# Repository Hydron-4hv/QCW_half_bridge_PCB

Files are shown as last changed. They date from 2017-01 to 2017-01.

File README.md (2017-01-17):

# QCW_half_bridge_PCB
Half bridge PCB for TO-247 IGBTs, intended for DRSSTC or general use, includes optional PCB mounted CT

Design notes:
- Intended for use with "QCW_MMC_PCB" and "GDT_PCB" located in my other repositories
- Have included a lot of different holes for various mounting requirements. Hole placement is intended to allow connection to the MMC PCB via brass standoff.
- Two solder locations are provided for connecting via the CT (with jumper wire through the middle of CT). This is for flexibility when stacking 2 PCBs - can pass a connection through using a standoff through the unusued hole.
- Electrolytic cap footprints provided for 3x 25mm dia. capaciors or 2x 35mm. These are only relevant when not using a buck modulator to control bus voltage.
- Footprints provided for various different DC bus capactiors - up to 8x high voltage ceramic, up to 2x 27.5mm leg spacing film, 2x 15/22.5mm leg spacing film 
- Various Fischer Elektronik SK 481 heatsinks can be used (with clips to hold IGBTs), either 2 separate heatsinks (suggest 37.5mm length) to avoid isolation requirements, or larger 50-84mm with isolation pads behind IGBTs. In all cases use an insulated washer for heatsink mounting screw, and consider adding kapton tape or similar to top layer to add isolation between heatsink and top layer tracks.
- Option to use 2 IGBTs in parallel for each position - if this is done then care should be taken chosing gate drive sharing resistors or suitable ferrite beads to try and match switching characteristics as closely as possible (footprints provided).
- Clearance/Creepage distances (~1mm, occasionally slightly less) are marginal for running at 400-600V. Would suggest taking care with flux residue etc, and use at own risk.

Changes intended for future revisions:
- Increase clearance as possible
- Strengthen holes around IGBT gate legs with reinforcing vias

Output notes:
- 3 different "PCB Variants" have been defined and output files generated as examples:
  - Single IGBT in each of upper and lower half bridge position, no CT, 2x 37.5mm SK481 heatsinks, no electrolytic caps
  - Single IGBTs in each of upper and lower half bridge position, CT mounted, 2x 37.5mm SK481 heatsinks, 2x 35mm dia. electrolytic caps fitted
  - Dual IGBTs in each of upper and lower half bridge position, CT mounted, 2x 37.5mm SK481 heatsinks, 3x 25mm dia. electrolytic caps fitted
- The "schematic" PDFs are located under "Reference outputs" and include a 3D model for viewing in compatible software (Adobe reader works, Foxit does not, unsure about others)
- BoM outputs have been provided but are of low quality, as I did not spend time fixing up the component parameters. The schematic should give whatever information is misssing.

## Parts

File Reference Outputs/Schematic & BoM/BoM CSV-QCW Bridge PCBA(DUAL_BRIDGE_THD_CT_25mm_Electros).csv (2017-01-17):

Designator | Comment | Description | Fitted | Footprint | LibRef | Quantity
C1 | B32774 | Capacitor | Not Fitted | B32774 5uF 800V | Cap | 0
C2, C3 | 560uF | WCAP-AIL8 Aluminum Electrolytic Capacitors, 560uF | Not Fitted | WCAP-AIL8_35x47 | WCAP-AIL8, 861101486027 | 0
C4, C5, C6, C7, C11, C12, C13, C14, C16, C17 | Capacitor |  | Fitted | 2220C, 1812C, 2220C, 1812C, 2220C, 1812C, 2220C, 1812C, Cap_multi_footprint, Cap_multi_footprint | Capacitor | 10
C8, C9, C10 | 270uF | WCAP-AIL8 Aluminum Electrolytic Capacitors, 270uF | Fitted | WCAP-AIL8_25x46 | WCAP-AIL8, 861101484015 | 3
C15 | B32774 | Capacitor | Fitted | B32774 5uF 800V | Cap | 1
D1, D3, D5, D7 | 60V 2A | SS26 Schottky rectifier | Fitted | DO-214AA_(SMB-J-BEND)_UNI | SS26 | 4
D2, D4, D6, D8 | 600 W, 24 VDC | WE-TVSP Power TVS Diode, bidirectional, 600 W, 24 VDC | Fitted | DO-214AA_Bidirectional | WE-TVSP DO-214AA, 824521241 | 4
HS1, HS2 | SK481_37.5mm HS |  | Fitted | SK 481 37.5, SK 481 37.5_FLIP | SK_481_37.5 | 2
J1 | 61202021621 | WR-BHD 2.54mm Male Box Header | Fitted | 61202021621 | 61202021621 | 1
L1, L2, L3, L4 | 32O | WE-CBF SMD EMI Suppression Ferrite Bead, 1206, 32O | Fitted | WE-CBF_1206_High Speed | WE-CBF, 7427921 | 4
Q1, Q2, Q3, Q4 |  | IGBT, TO-247, Vertical | Fitted | TO-247 | TO-247_IGBT_V | 4
R3, R4, R7, R8, R11, R12, R16, R17 | Res2 | Resistor | Fitted | RES_2512 | Res2 | 8
TX1 | 56050C 50:1 CT | Murata 56050C 10A 50:1 CT | Fitted | KMP_5600_ALT | 56050C_ALT | 1

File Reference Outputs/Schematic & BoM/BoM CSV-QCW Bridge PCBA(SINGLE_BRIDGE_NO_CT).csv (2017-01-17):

Designator | Comment | Description | Fitted | Footprint | LibRef | Quantity
C1 | B32774 | Capacitor | Not Fitted | B32774 5uF 800V | Cap | 0
C2, C3 | 560uF | WCAP-AIL8 Aluminum Electrolytic Capacitors, 560uF | Not Fitted | WCAP-AIL8_35x47 | WCAP-AIL8, 861101486027 | 0
C4, C5, C6, C7, C11, C12, C13, C14, C16, C17 | Capacitor |  | Fitted | 2220C, 1812C, 2220C, 1812C, 2220C, 1812C, 2220C, 1812C, Cap_multi_footprint, Cap_multi_footprint | Capacitor | 10
C8, C9, C10 | 270uF | WCAP-AIL8 Aluminum Electrolytic Capacitors, 270uF | Not Fitted | WCAP-AIL8_25x46 | WCAP-AIL8, 861101484015 | 0
C15 | B32774 | Capacitor | Fitted | B32774 5uF 800V | Cap | 1
D1, D3 | 60V 2A | SS26 Schottky rectifier | Fitted | DO-214AA_(SMB-J-BEND)_UNI | SS26 | 2
D2, D4 | 600 W, 24 VDC | WE-TVSP Power TVS Diode, bidirectional, 600 W, 24 VDC | Fitted | DO-214AA_Bidirectional | WE-TVSP DO-214AA, 824521241 | 2
D5, D7 | 60V 2A | SS26 Schottky rectifier | Not Fitted | DO-214AA_(SMB-J-BEND)_UNI | SS26 | 0
D6, D8 | 600 W, 24 VDC | WE-TVSP Power TVS Diode, bidirectional, 600 W, 24 VDC | Not Fitted | DO-214AA_Bidirectional | WE-TVSP DO-214AA, 824521241 | 0
HS1, HS2 | SK481_37.5mm HS |  | Fitted | SK 481 37.5, SK 481 37.5_FLIP | SK_481_37.5 | 2
J1 | 61202021621 | WR-BHD 2.54mm Male Box Header | Fitted | 61202021621 | 61202021621 | 1
L1, L2 | 32O | WE-CBF SMD EMI Suppression Ferrite Bead, 1206, 32O | Fitted | WE-CBF_1206_High Speed | WE-CBF, 7427921 | 2
L3, L4 | 32O | WE-CBF SMD EMI Suppression Ferrite Bead, 1206, 32O | Not Fitted | WE-CBF_1206_High Speed | WE-CBF, 7427921 | 0
Q1, Q2 |  | IGBT, TO-247, Vertical | Fitted | TO-247 | TO-247_IGBT_V | 2
Q3, Q4 |  | IGBT, TO-247, Vertical | Not Fitted | TO-247 | TO-247_IGBT_V | 0
R3, R4, R7, R8 | Res2 | Resistor | Fitted | RES_2512 | Res2 | 4
R11, R12, R16, R17 | Res2 | Resistor | Not Fitted | RES_2512 | Res2 | 0
TX1 | 56050C 50:1 CT | Murata 56050C 10A 50:1 CT | Not Fitted | KMP_5600_ALT | 56050C_ALT | 0

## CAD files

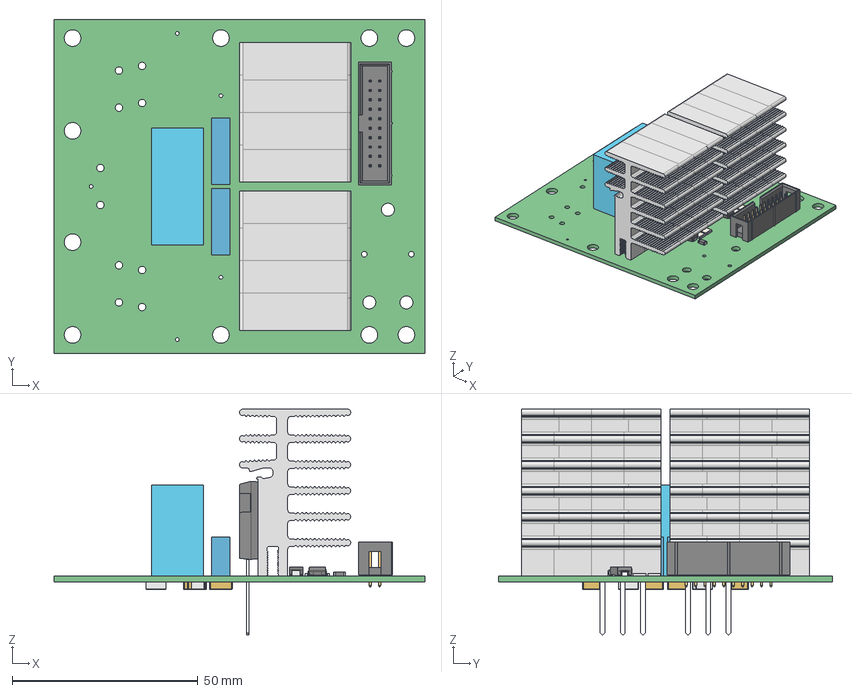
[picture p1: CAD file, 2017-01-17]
Reference Outputs/Mechanical/Export STEP Model of complete PCB_QCW Bridge PCBA-(SINGLE_BRIDGE_NO_CT).step
100.0 x 90.0 x 60.9 mm
BoardQCW_Bridge_PCBA
6120xx21621_PIN x 20
Extruded x 15
sk481 x 8
DO-214AA_Bidirectional x 2
Open_CASCADE_STEP_translator_6.8_3.1.1 x 2
Lead x 4
User_Library-TO-247_CASE_340L-02_Vertical_1 x 2
User_Library-TO-247_CASE_340L-02_Vertical_2 x 2
User_Library-TO-247_CASE_340L-02_Vertical_3 x 2
User_Library-TO-247_CASE_340L-02_Vertical_4 x 2
L\X2\00F6\X0\tende x 4
Open_CASCADE_STEP_translator_6.8_6.1.1 x 4
Open_CASCADE_STEP_translator_6.8_6.1.2 x 4
Open_CASCADE_STEP_translator_6.8_6.2.1 x 4
Open_CASCADE_STEP_translator_6.8_4.1.1 x 4
Open_CASCADE_STEP_translator_6.8_4.1.2 x 4
Open_CASCADE_STEP_translator_6.8_4.2.1 x 4

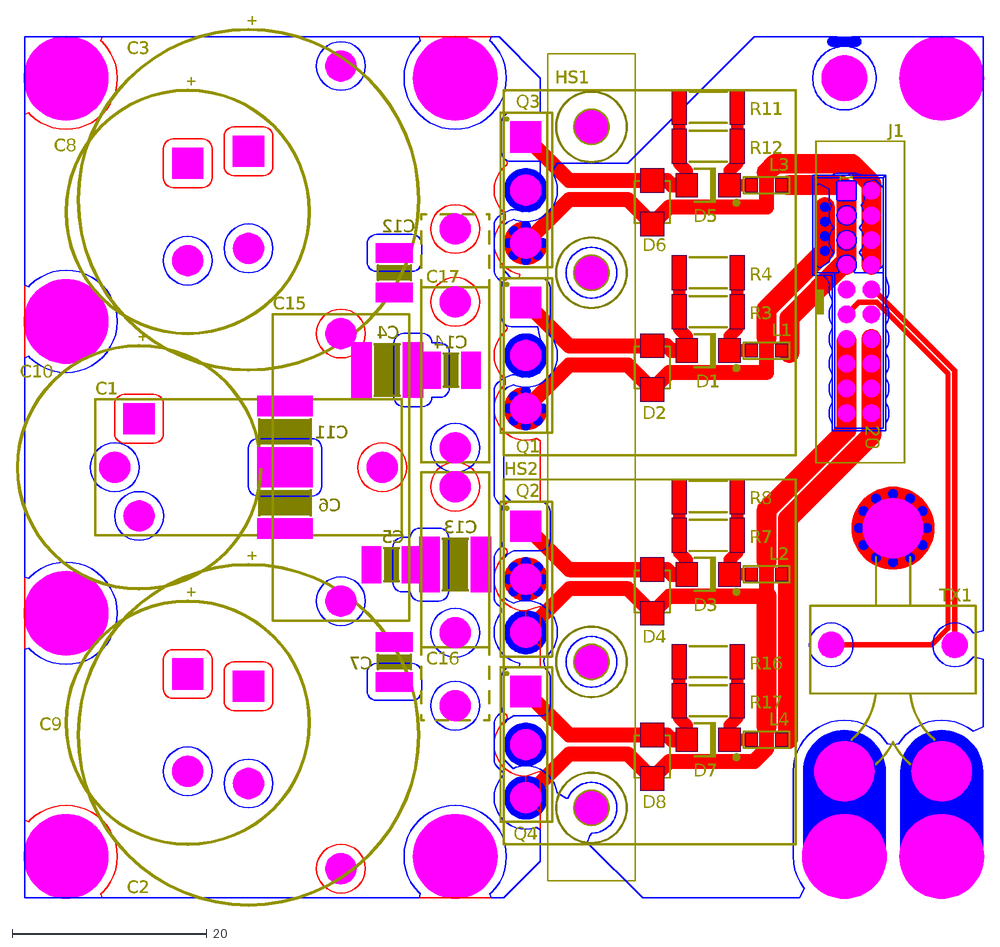
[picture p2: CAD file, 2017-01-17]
Reference Outputs/Mechanical/QCW Bridge PCBA.DXF
C3
C2
D7
TX1
J1
R17
R16
R12
R11
R8
R7
R4
R3
HS2
HS1
D8
D6
D5
Q4
Q3
D4
D3
D2
D1
Q1
Q2
C1
L1
L2
L3
L4
C4
C5
C6
C7
C8
C9
C10
C11
C12
C13
C14
C15
C16
C17

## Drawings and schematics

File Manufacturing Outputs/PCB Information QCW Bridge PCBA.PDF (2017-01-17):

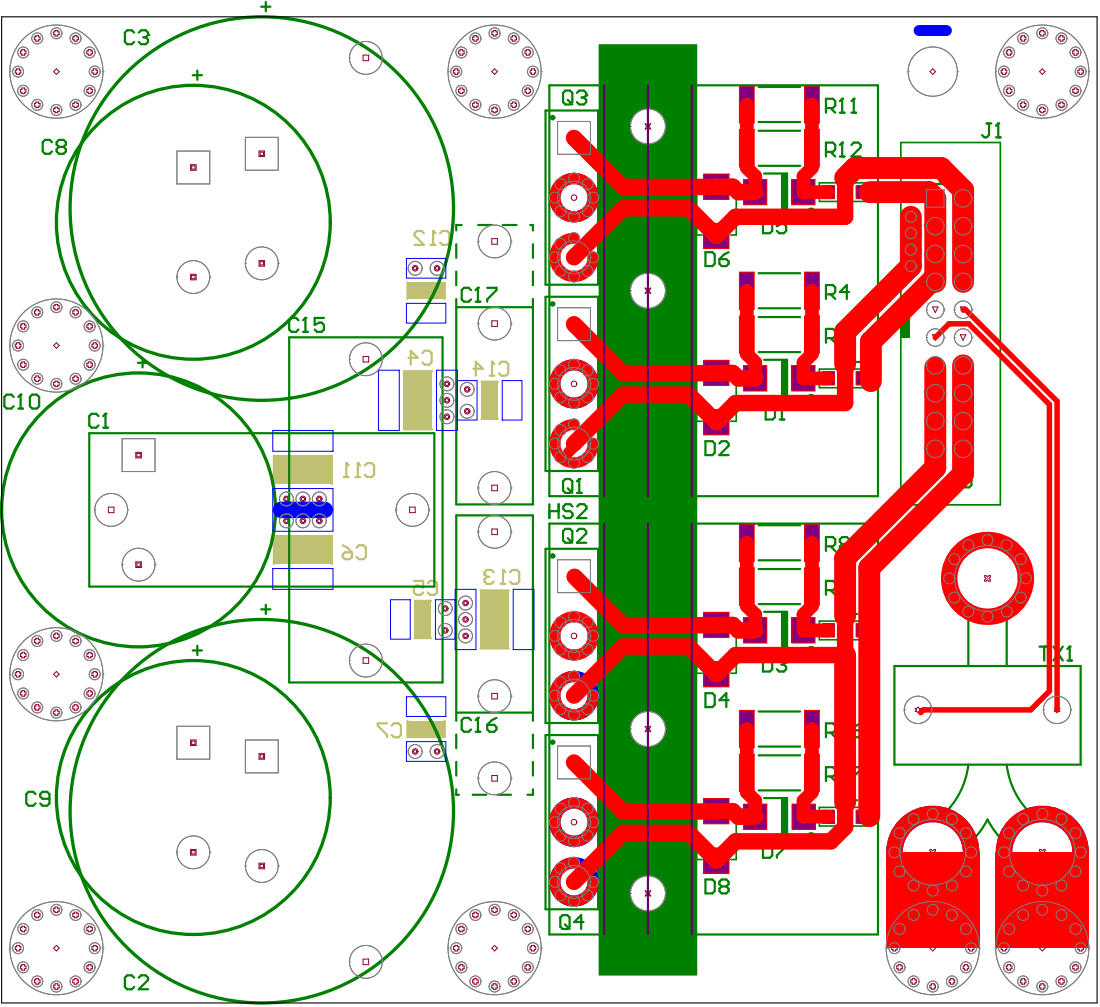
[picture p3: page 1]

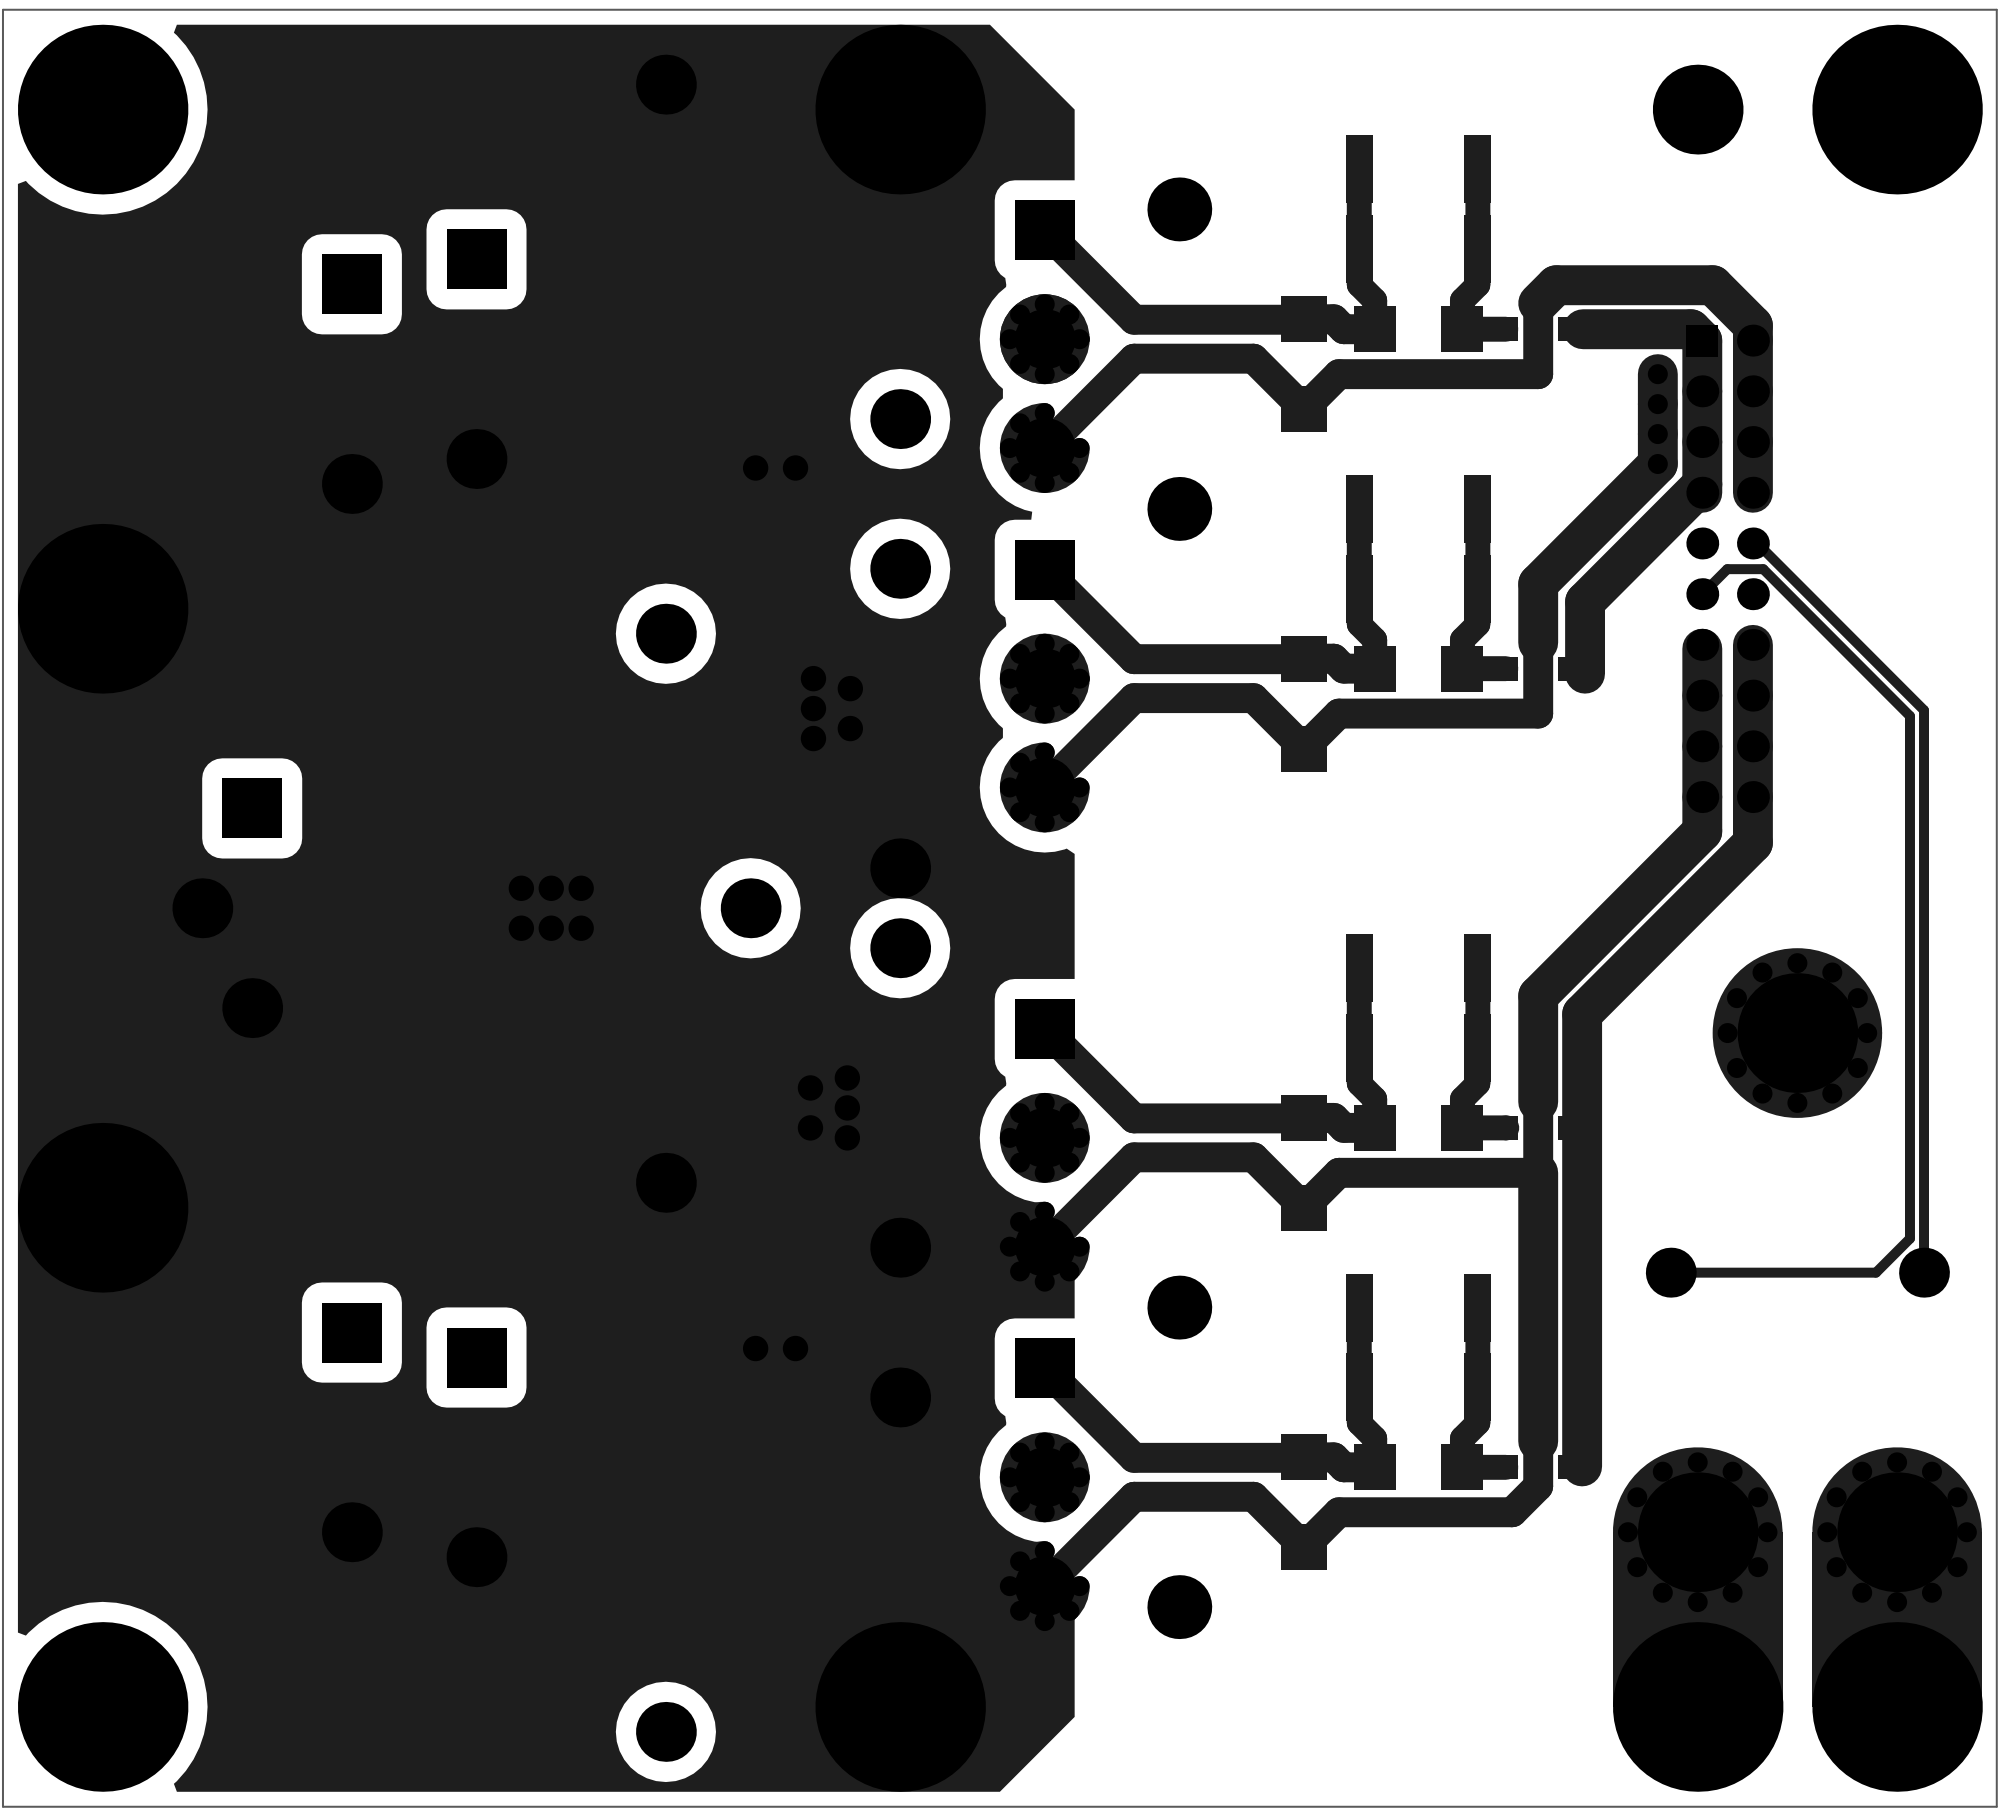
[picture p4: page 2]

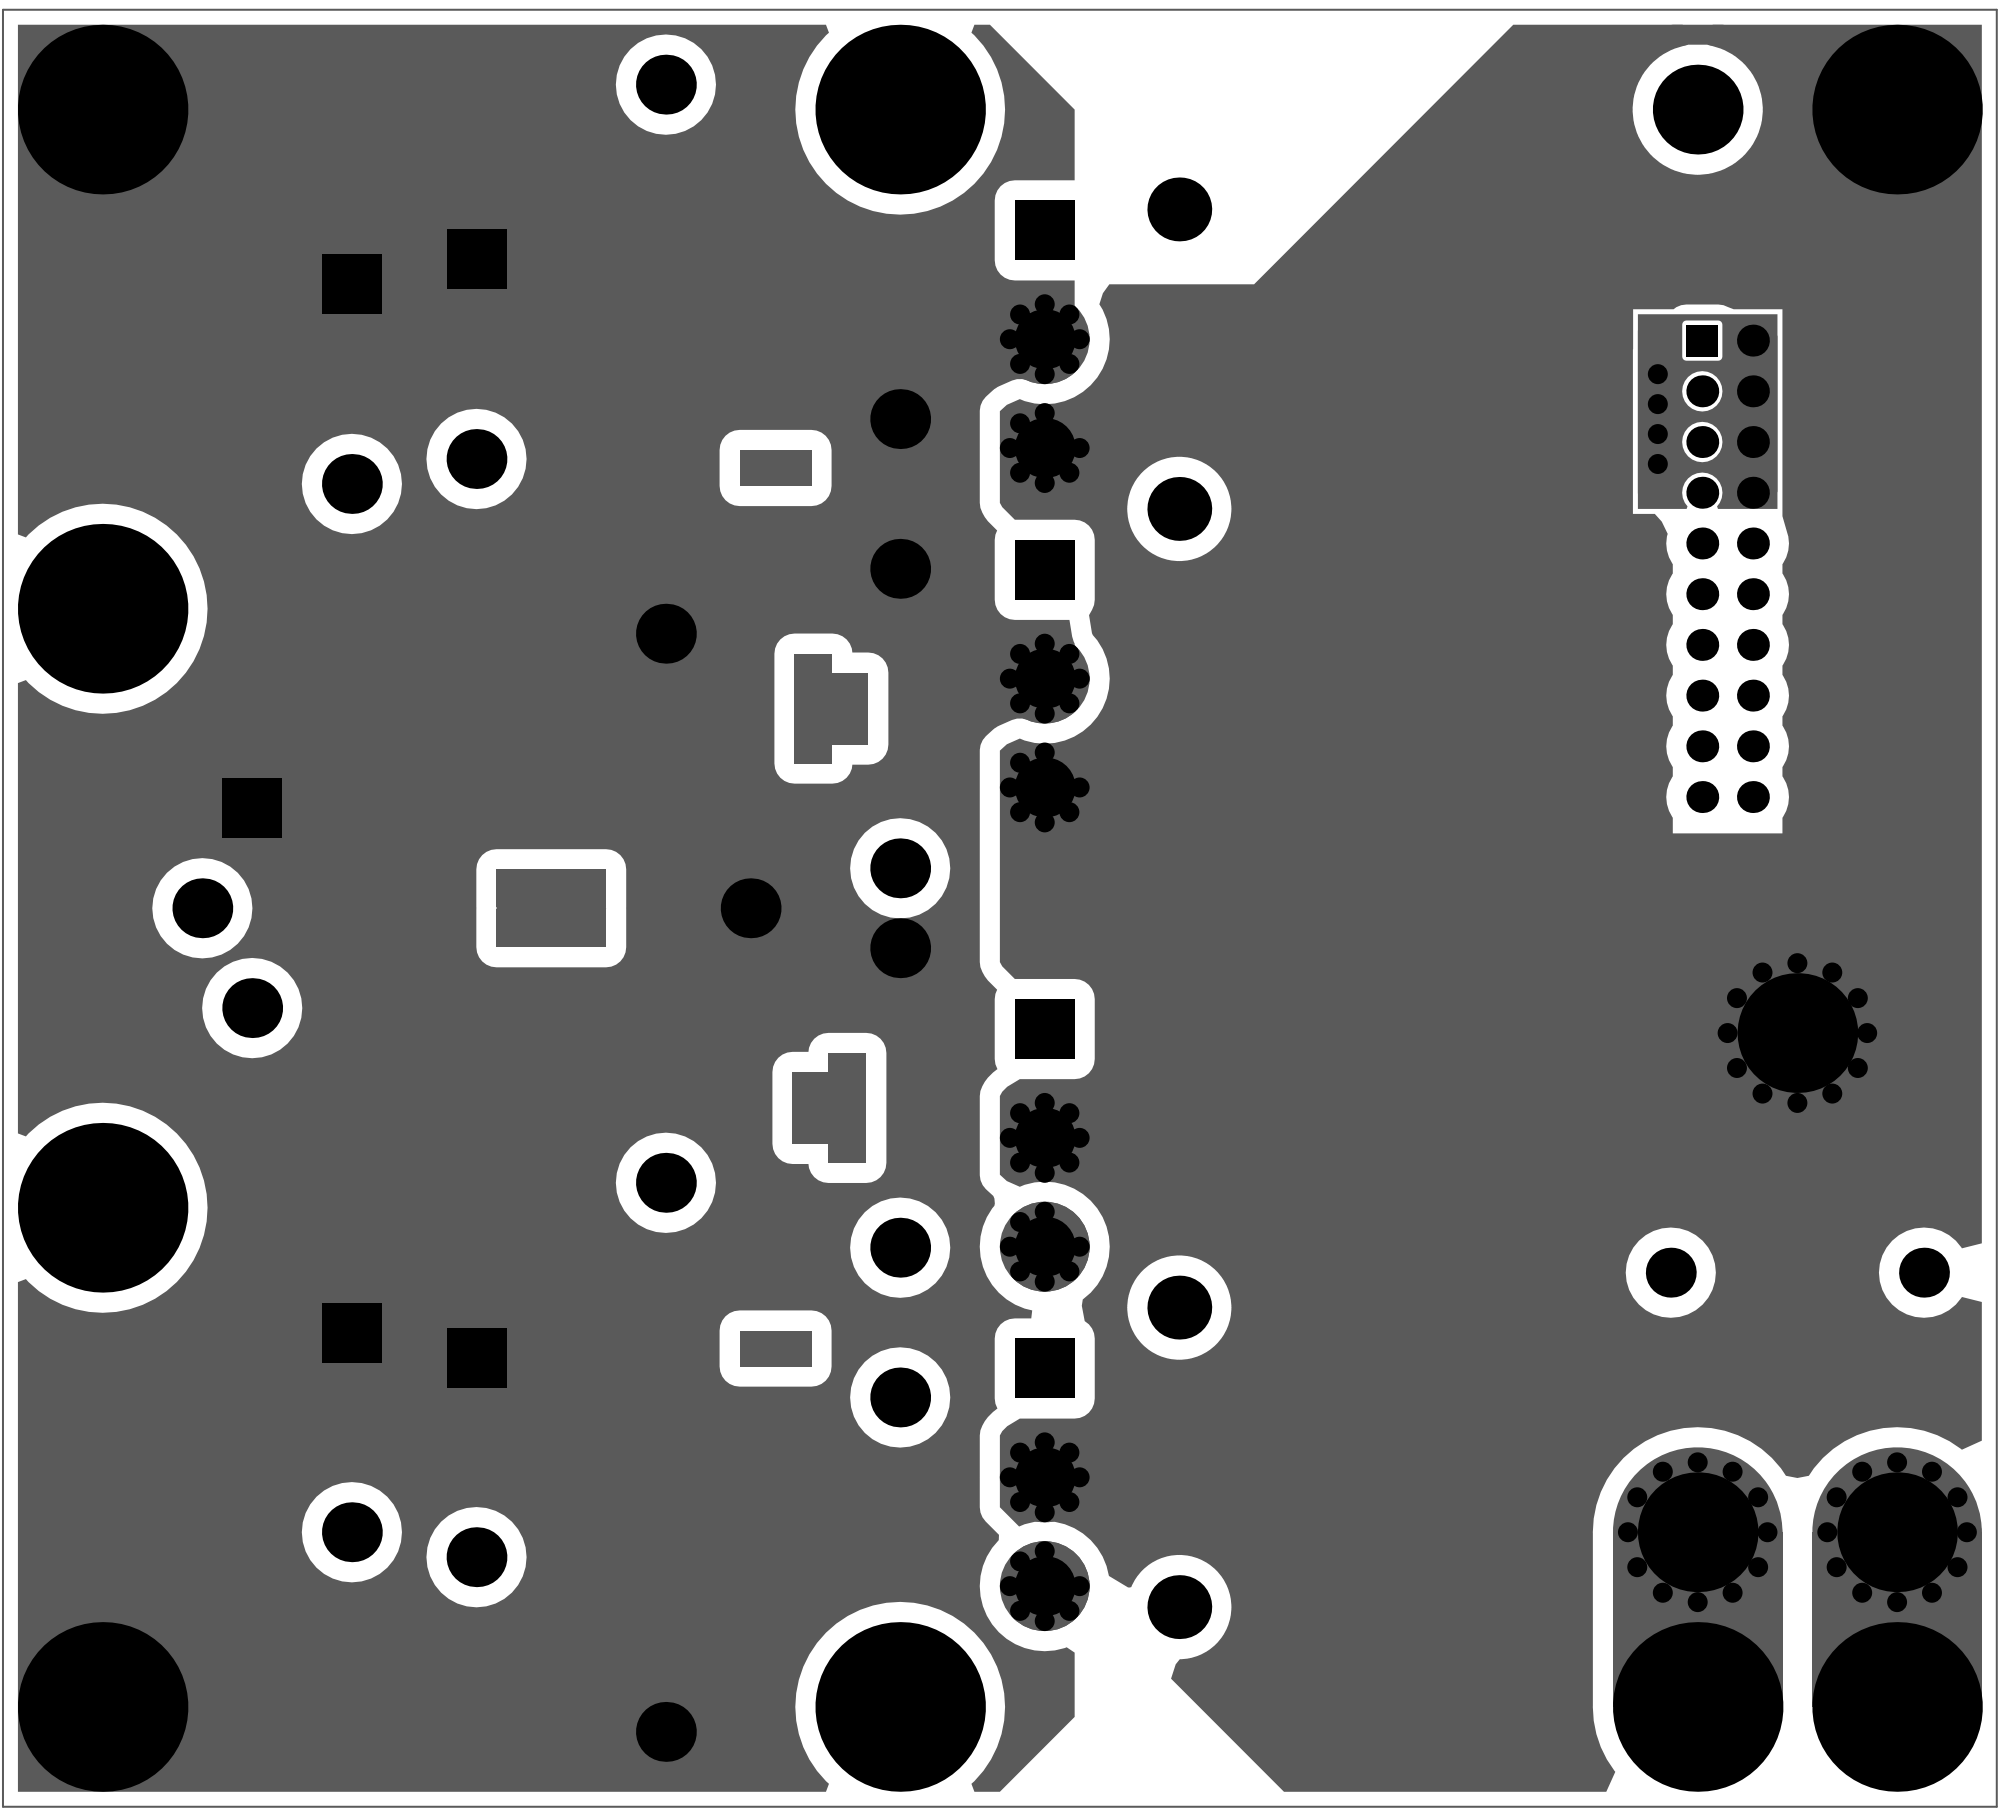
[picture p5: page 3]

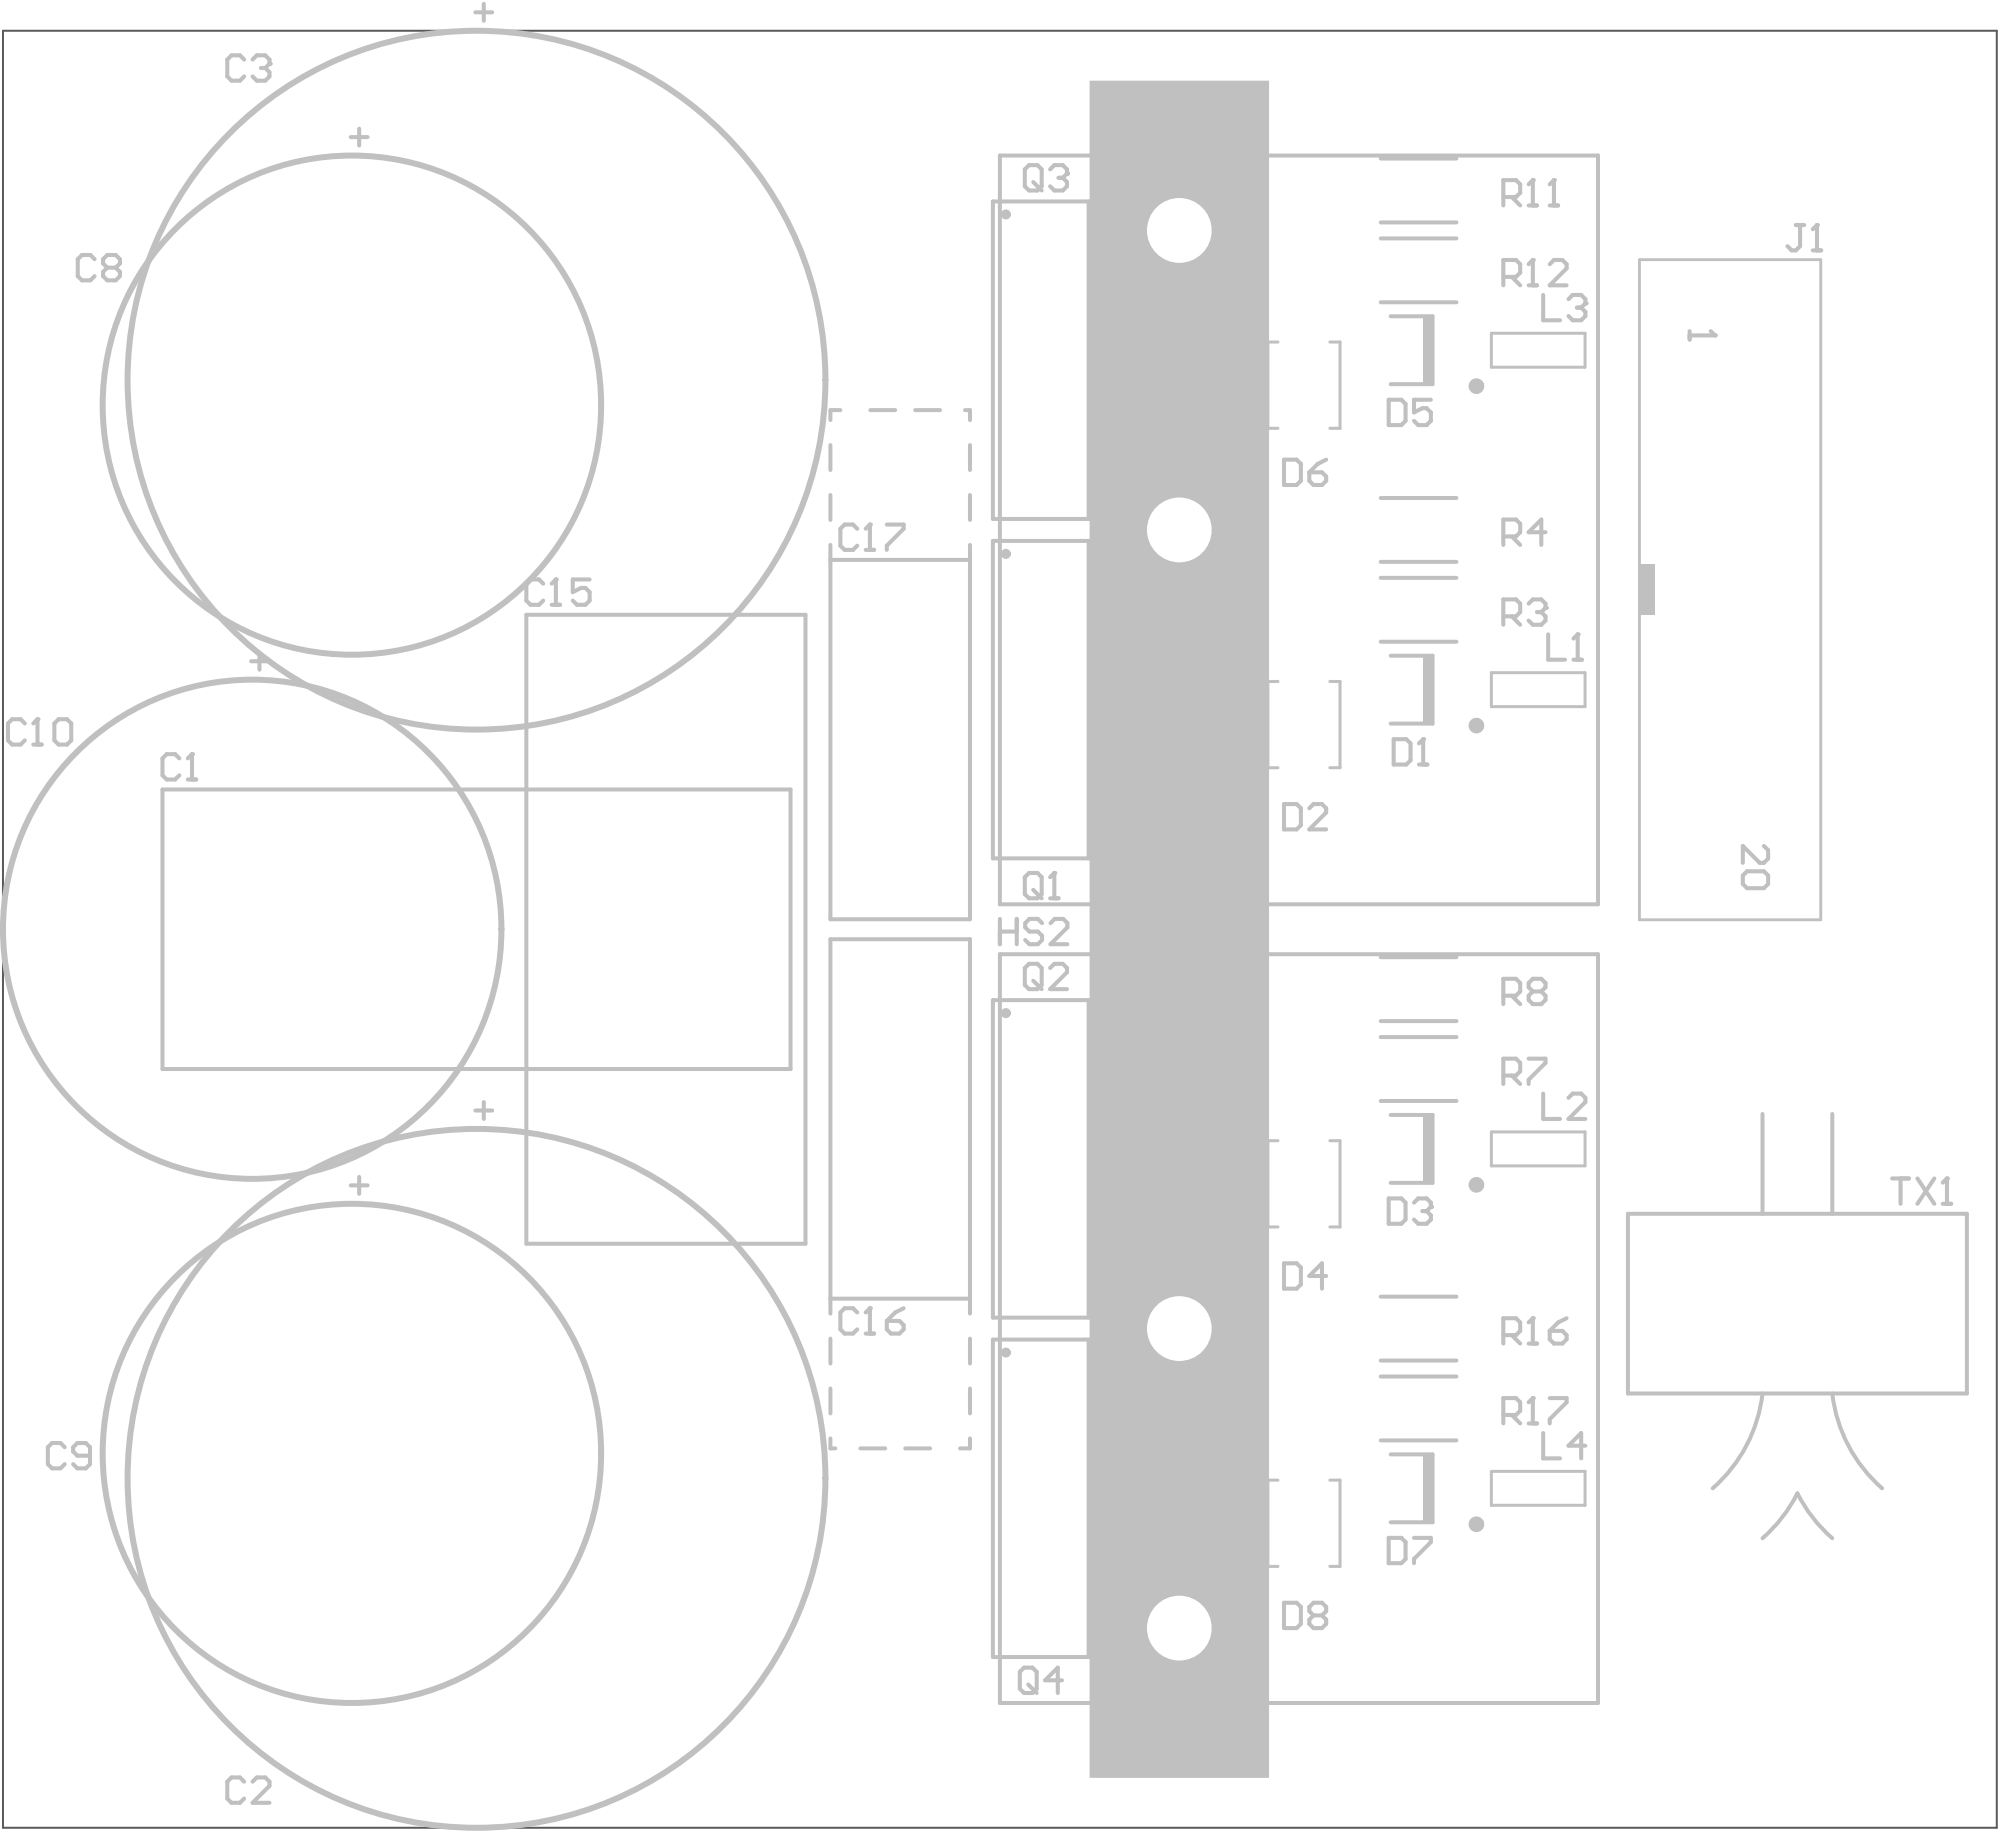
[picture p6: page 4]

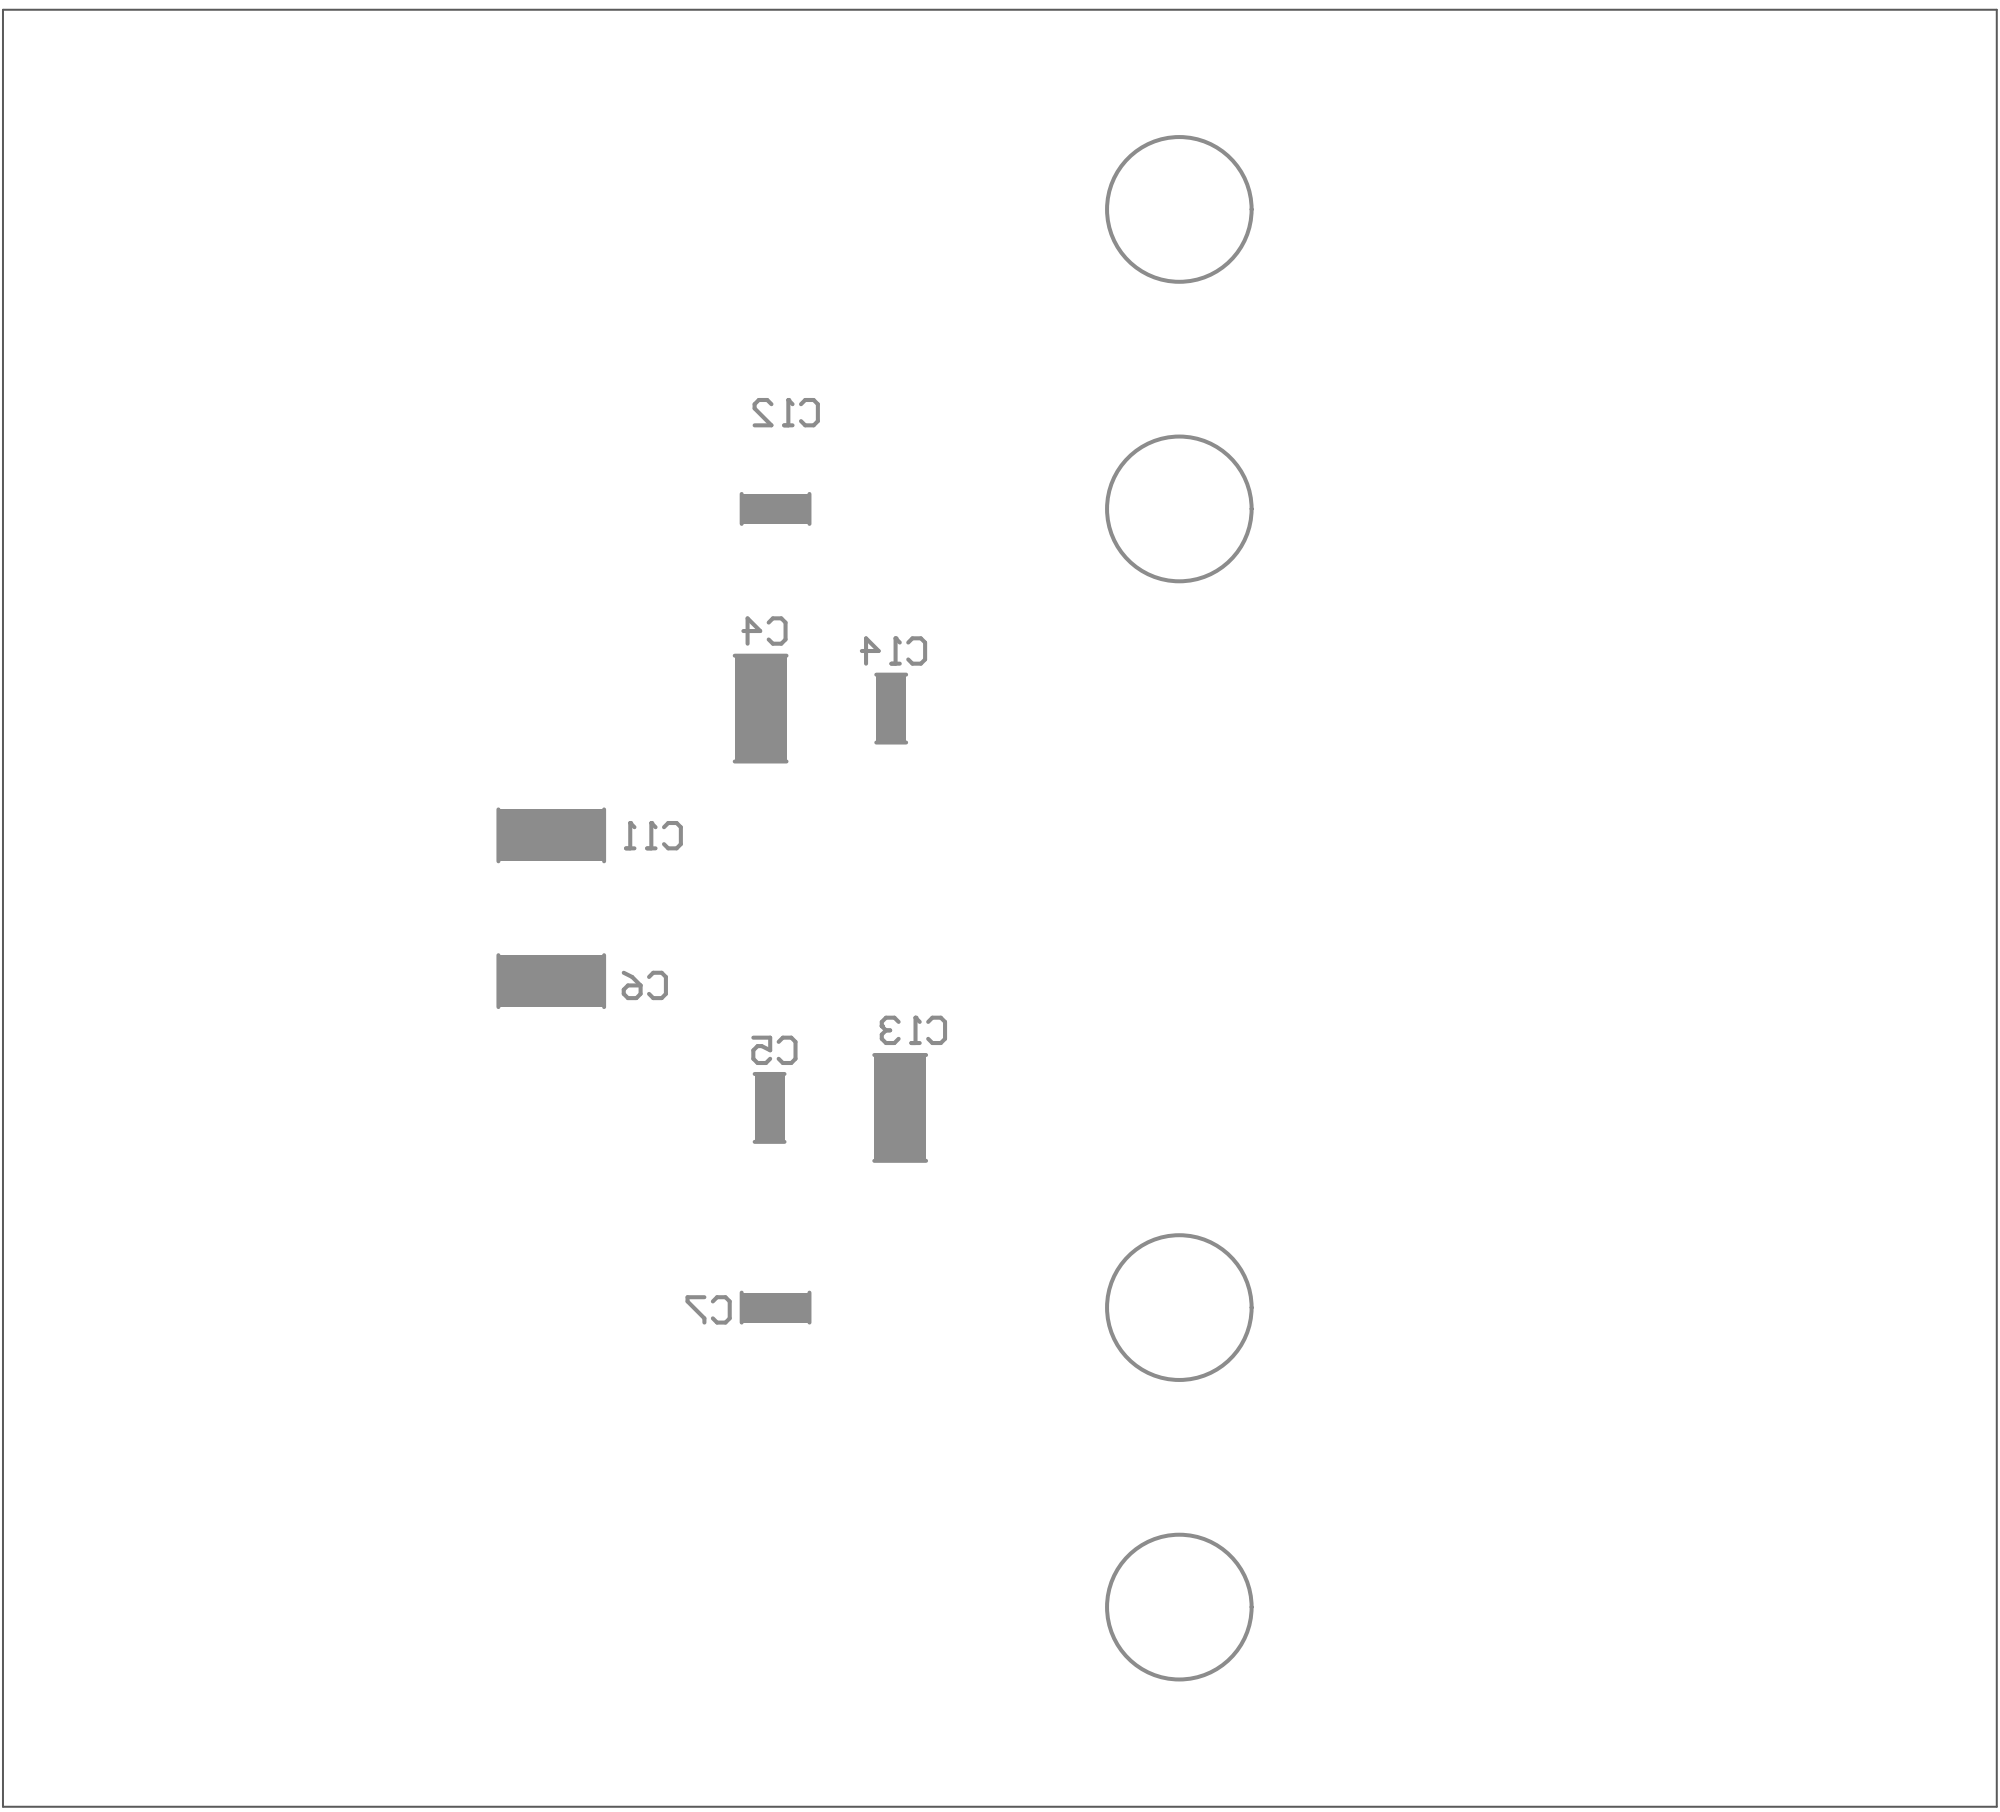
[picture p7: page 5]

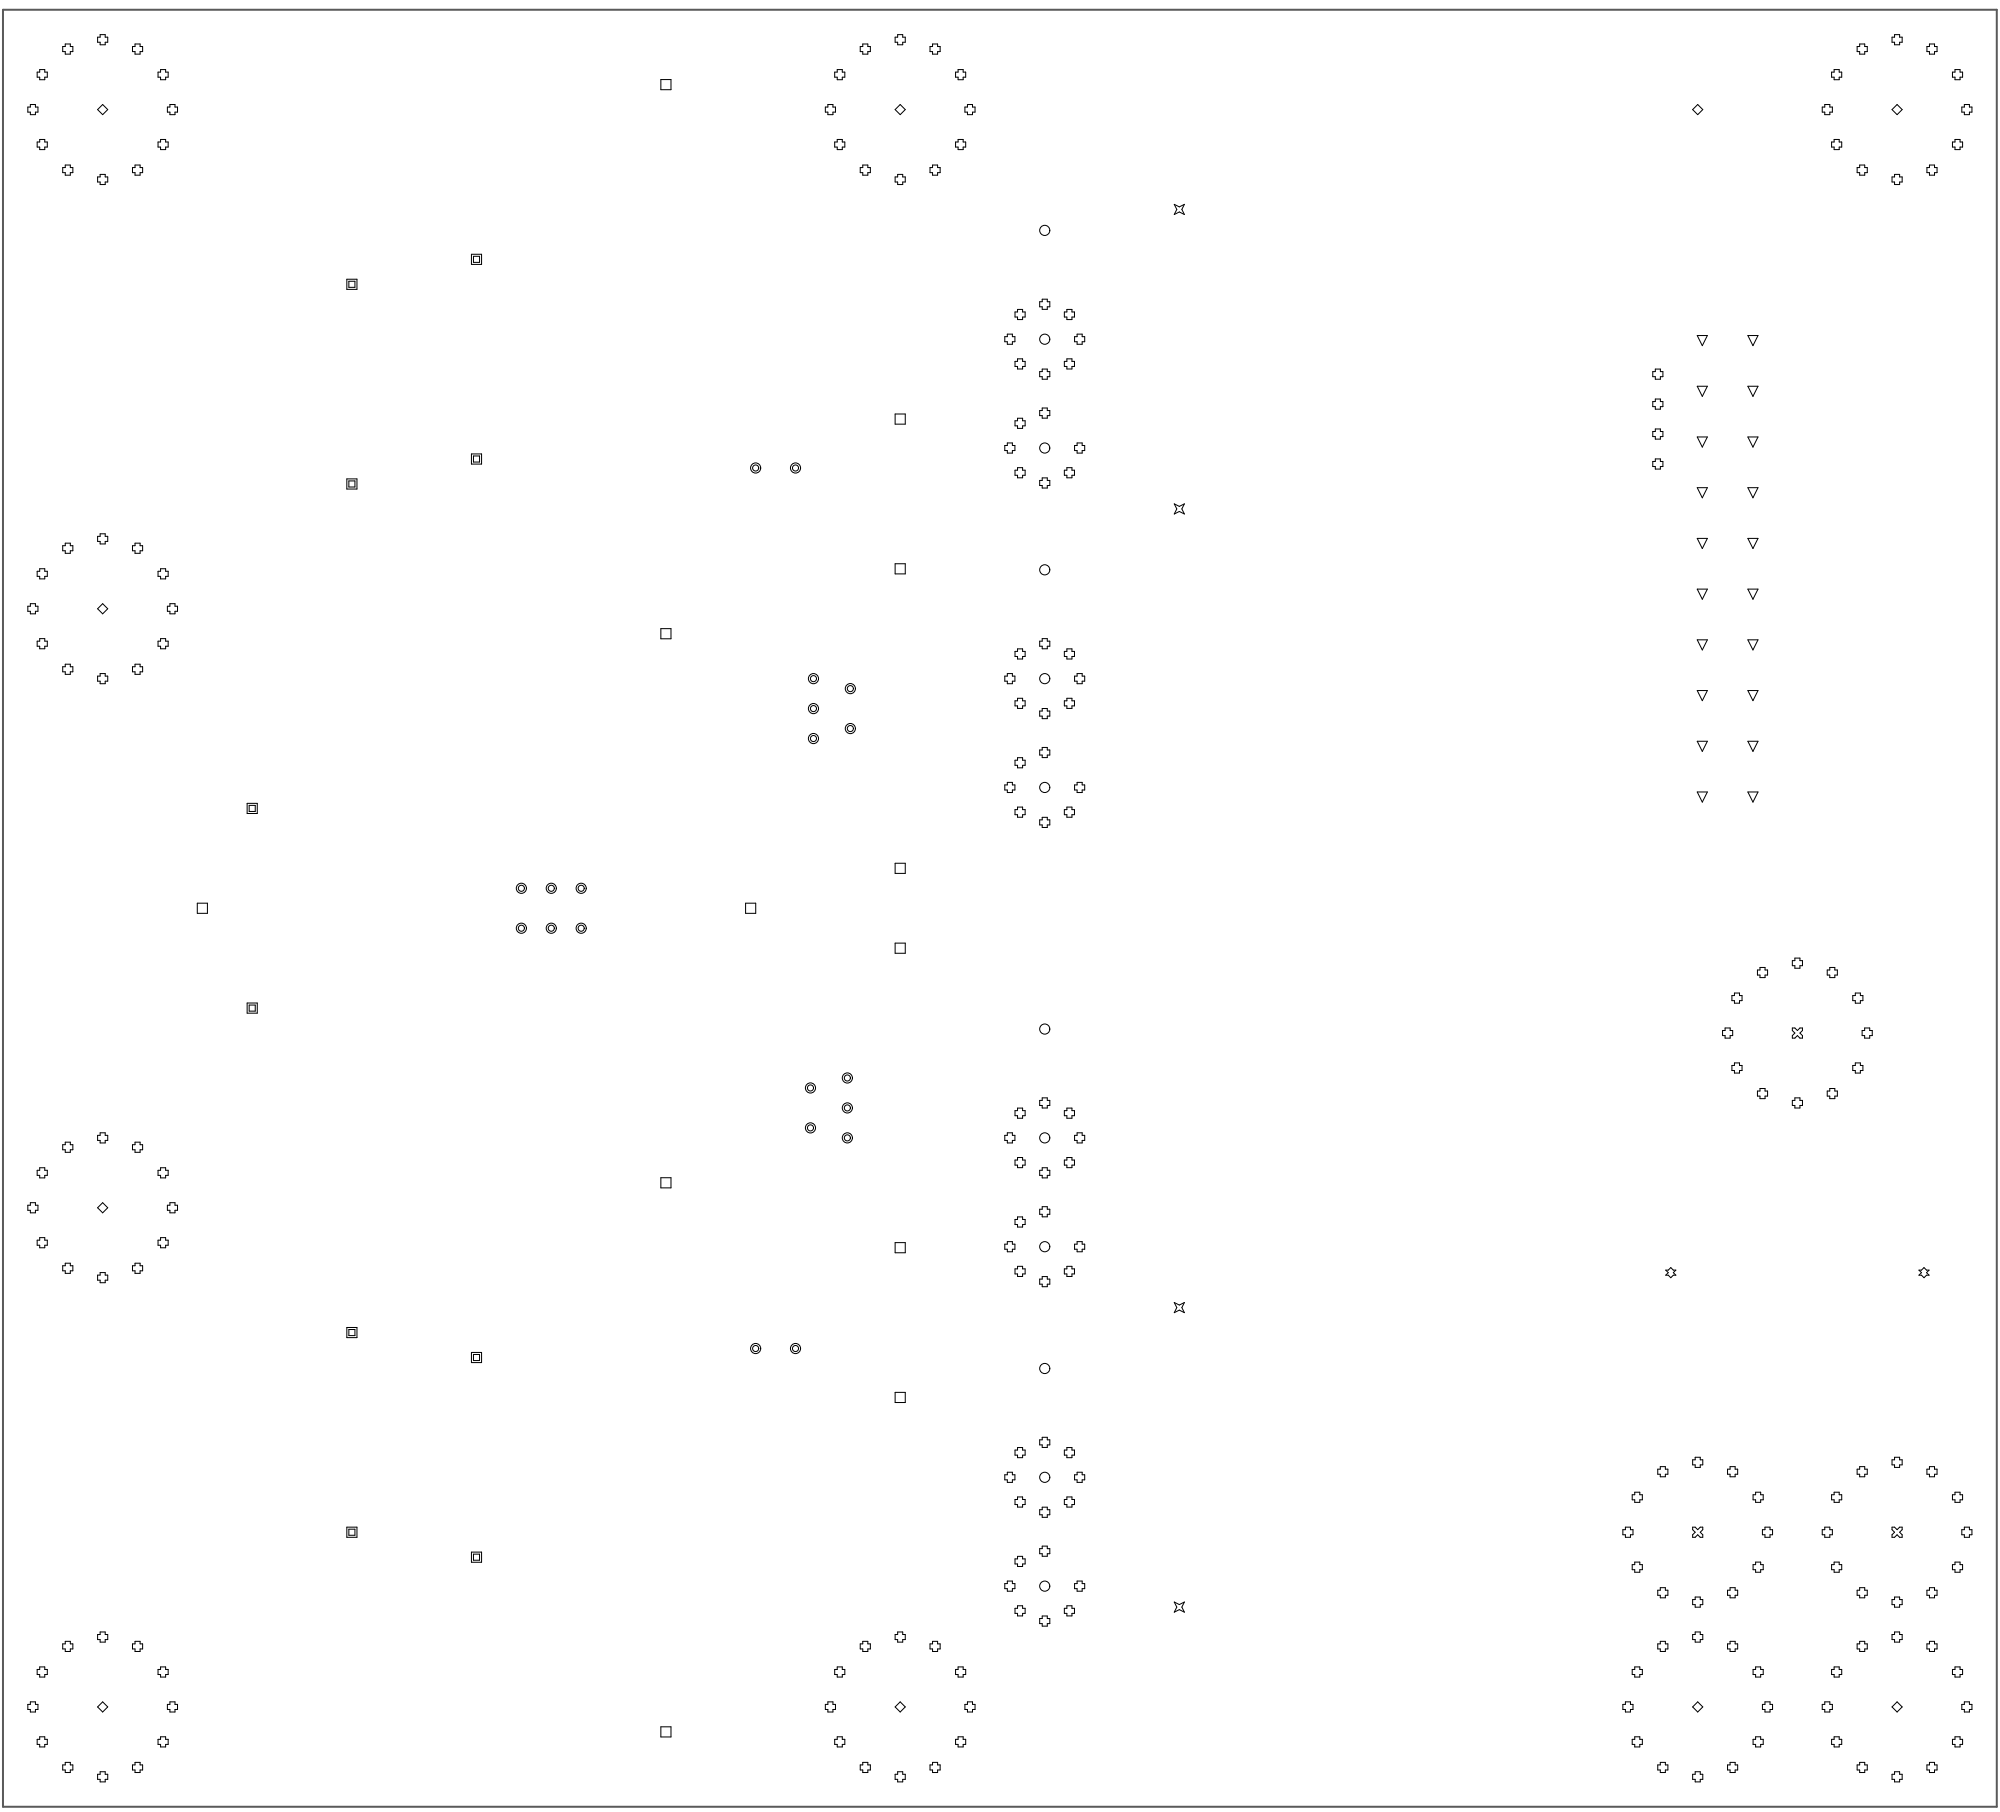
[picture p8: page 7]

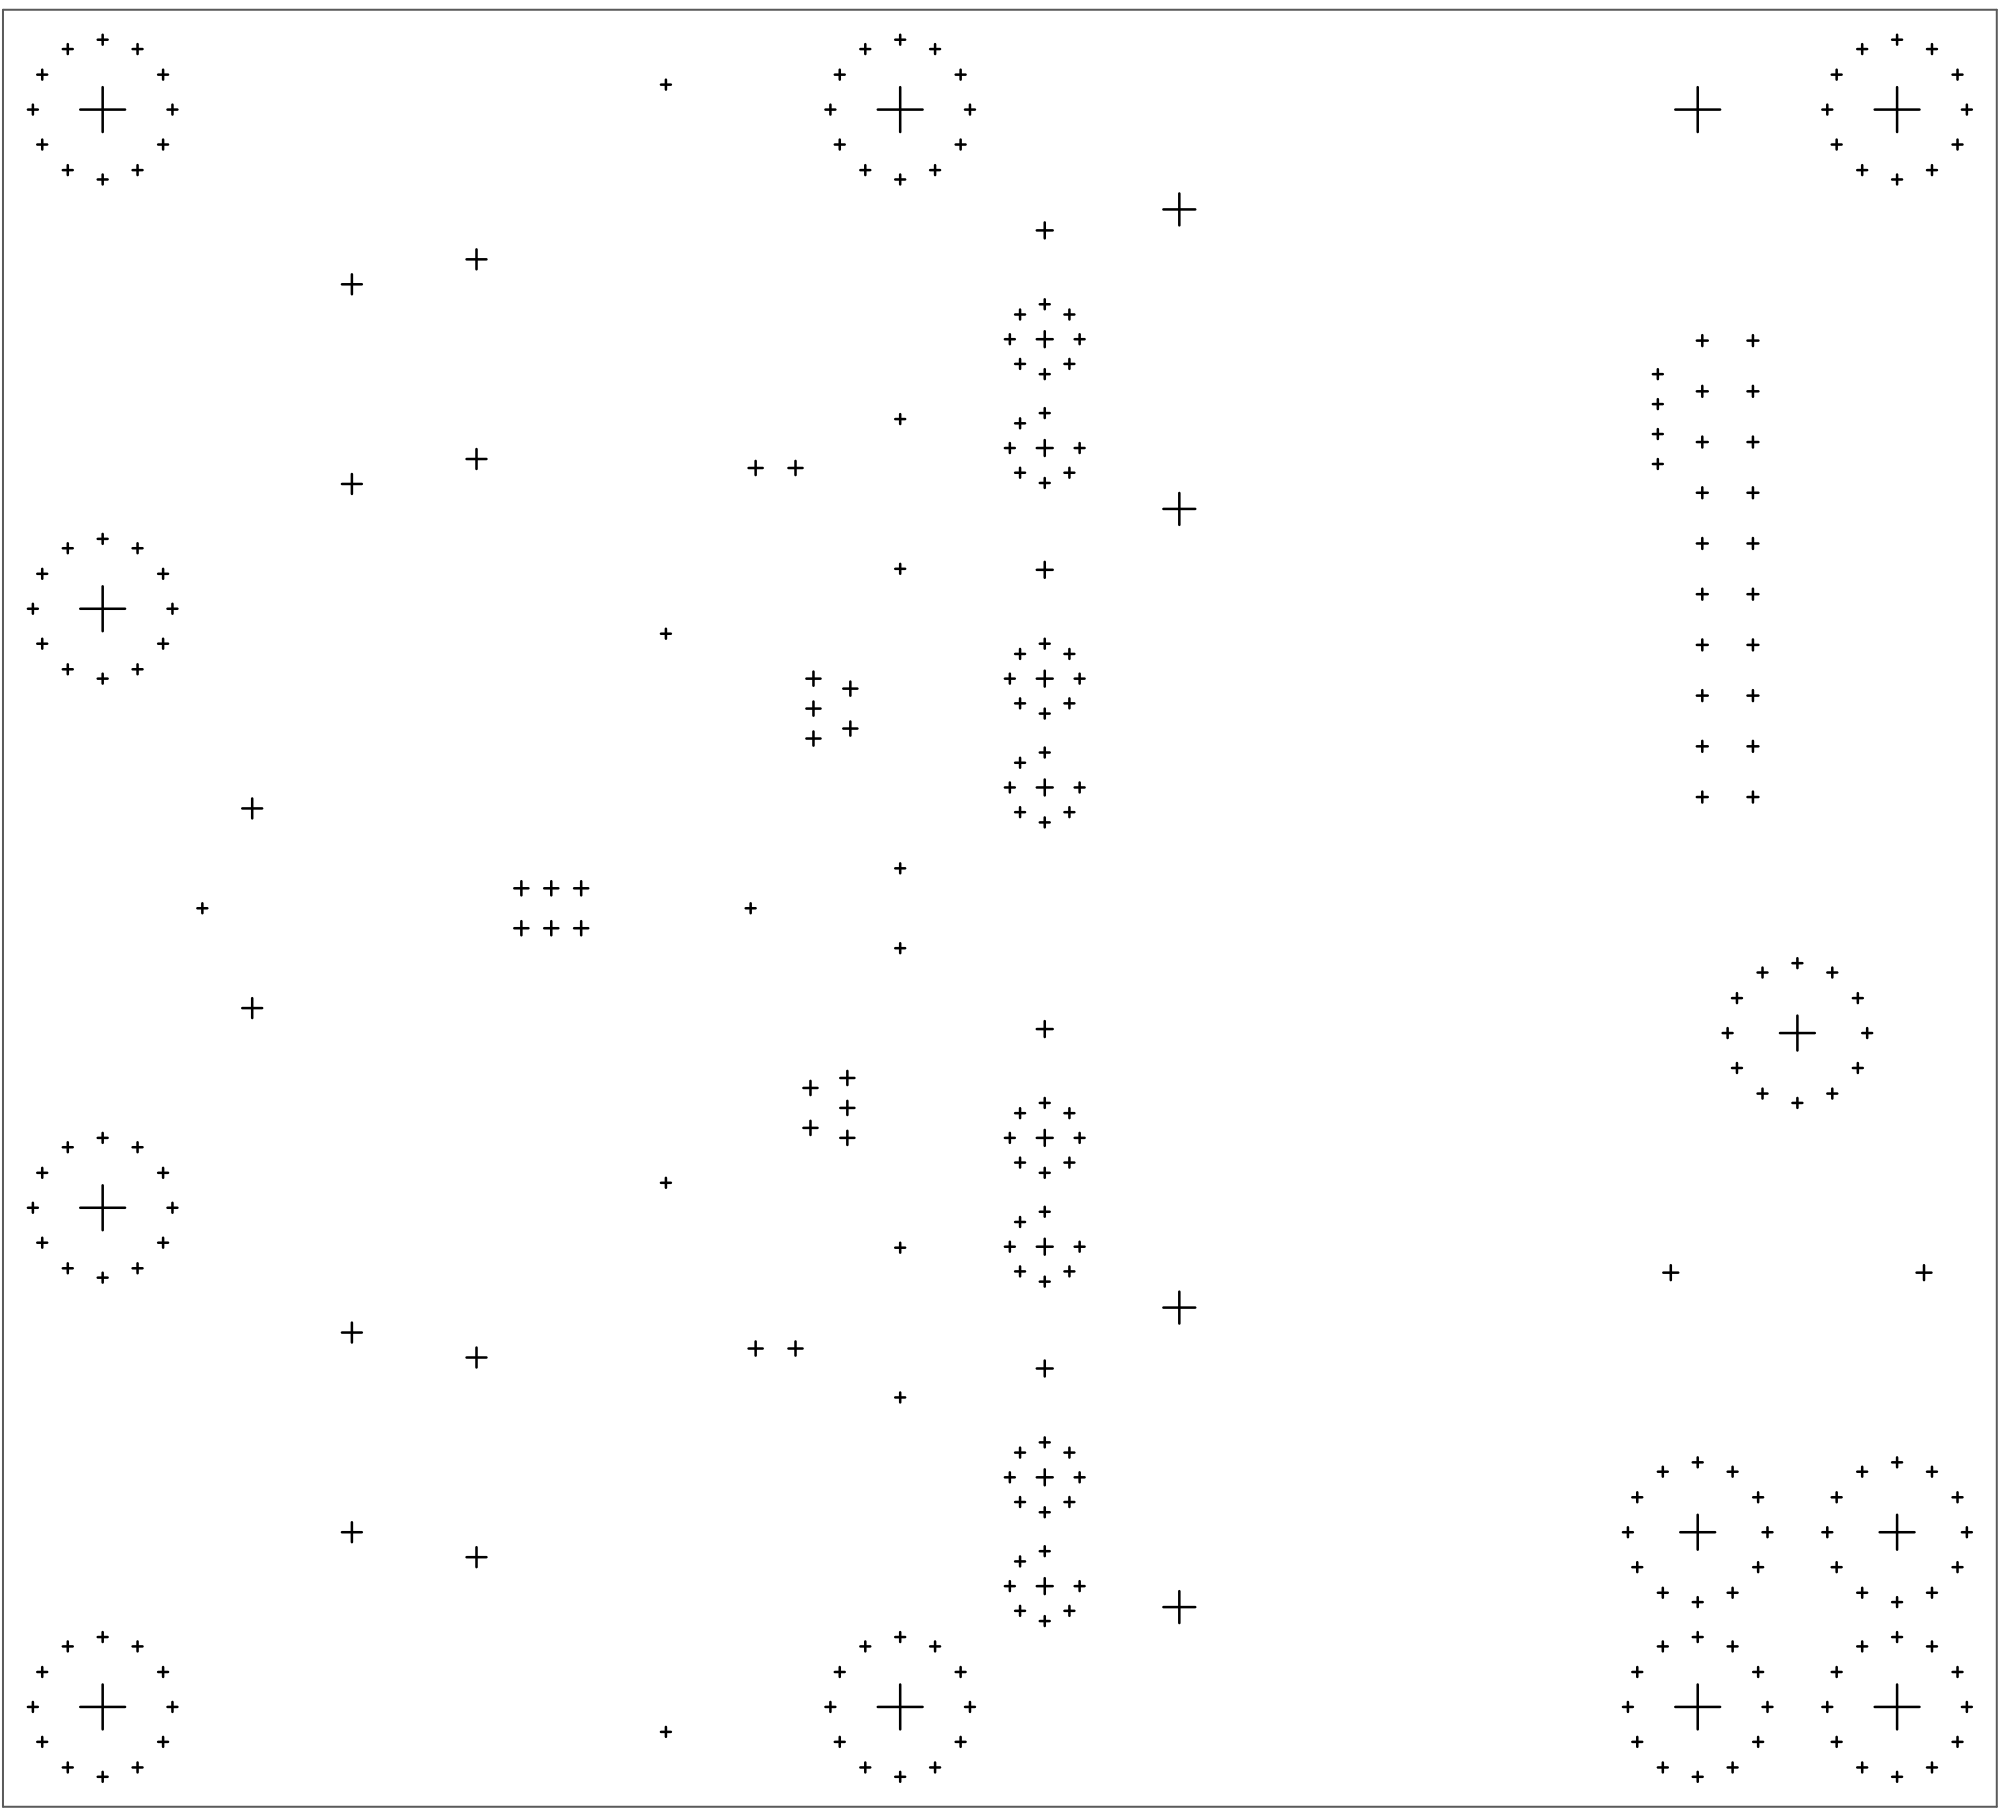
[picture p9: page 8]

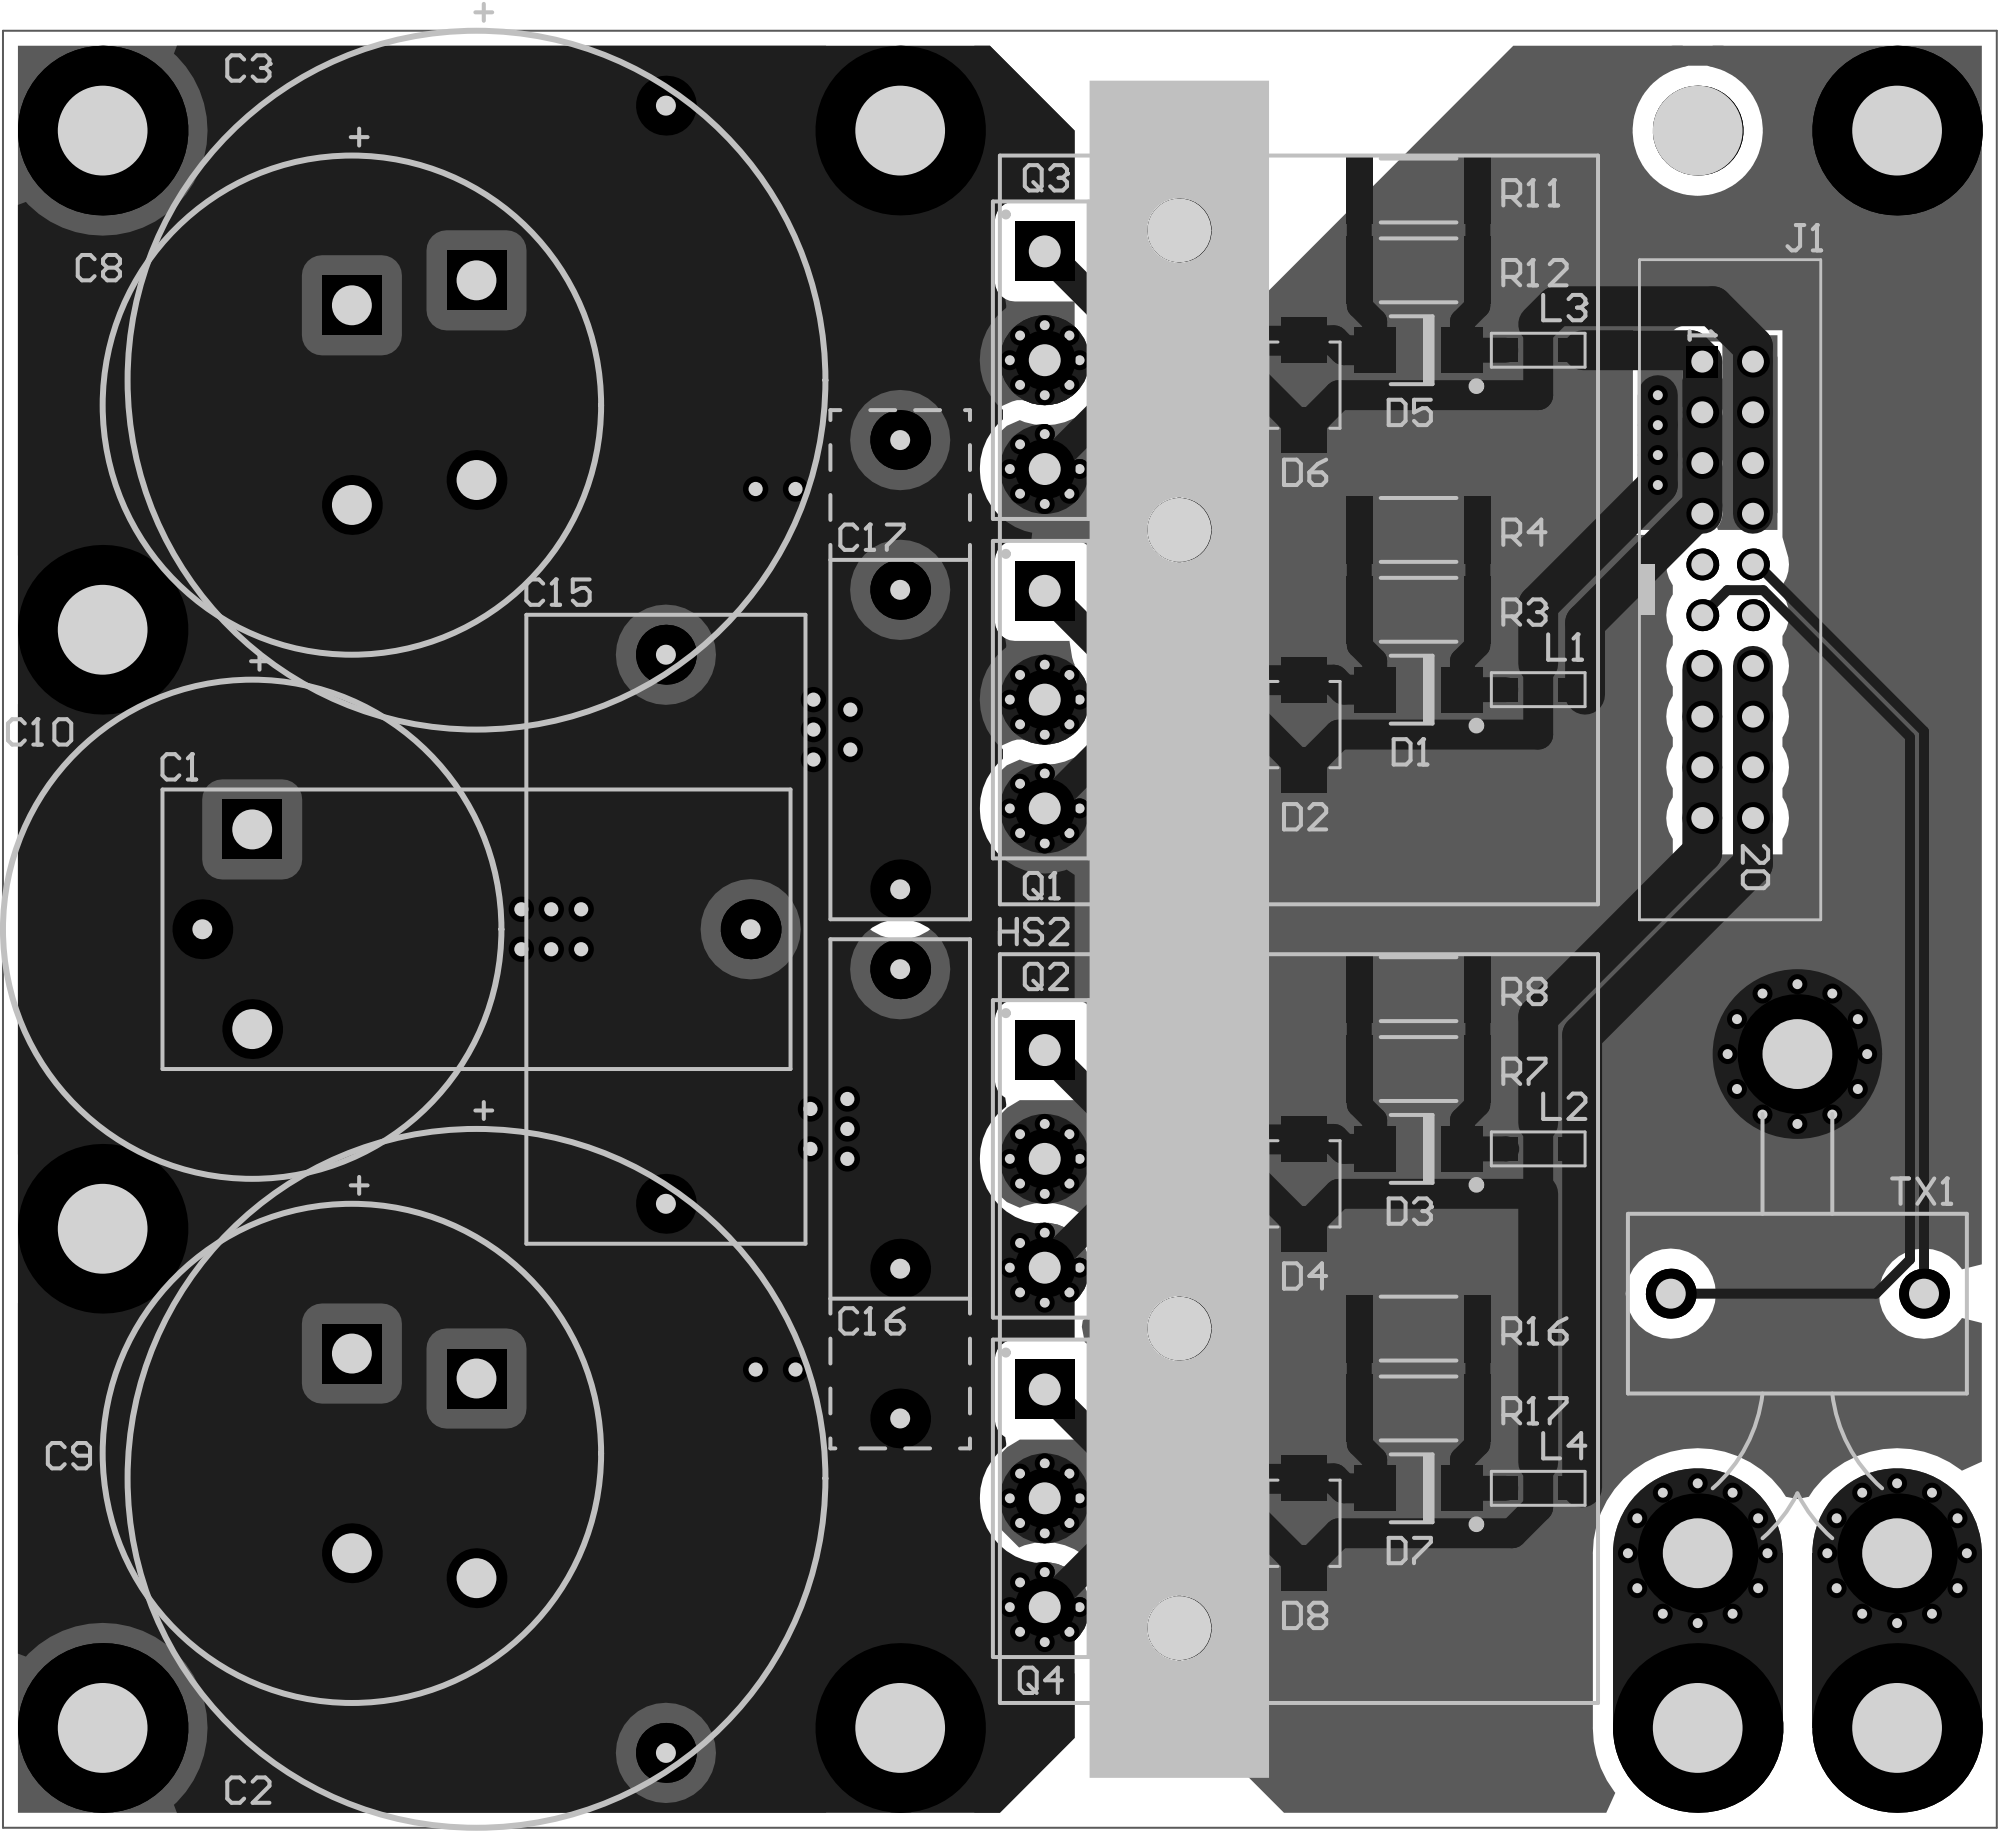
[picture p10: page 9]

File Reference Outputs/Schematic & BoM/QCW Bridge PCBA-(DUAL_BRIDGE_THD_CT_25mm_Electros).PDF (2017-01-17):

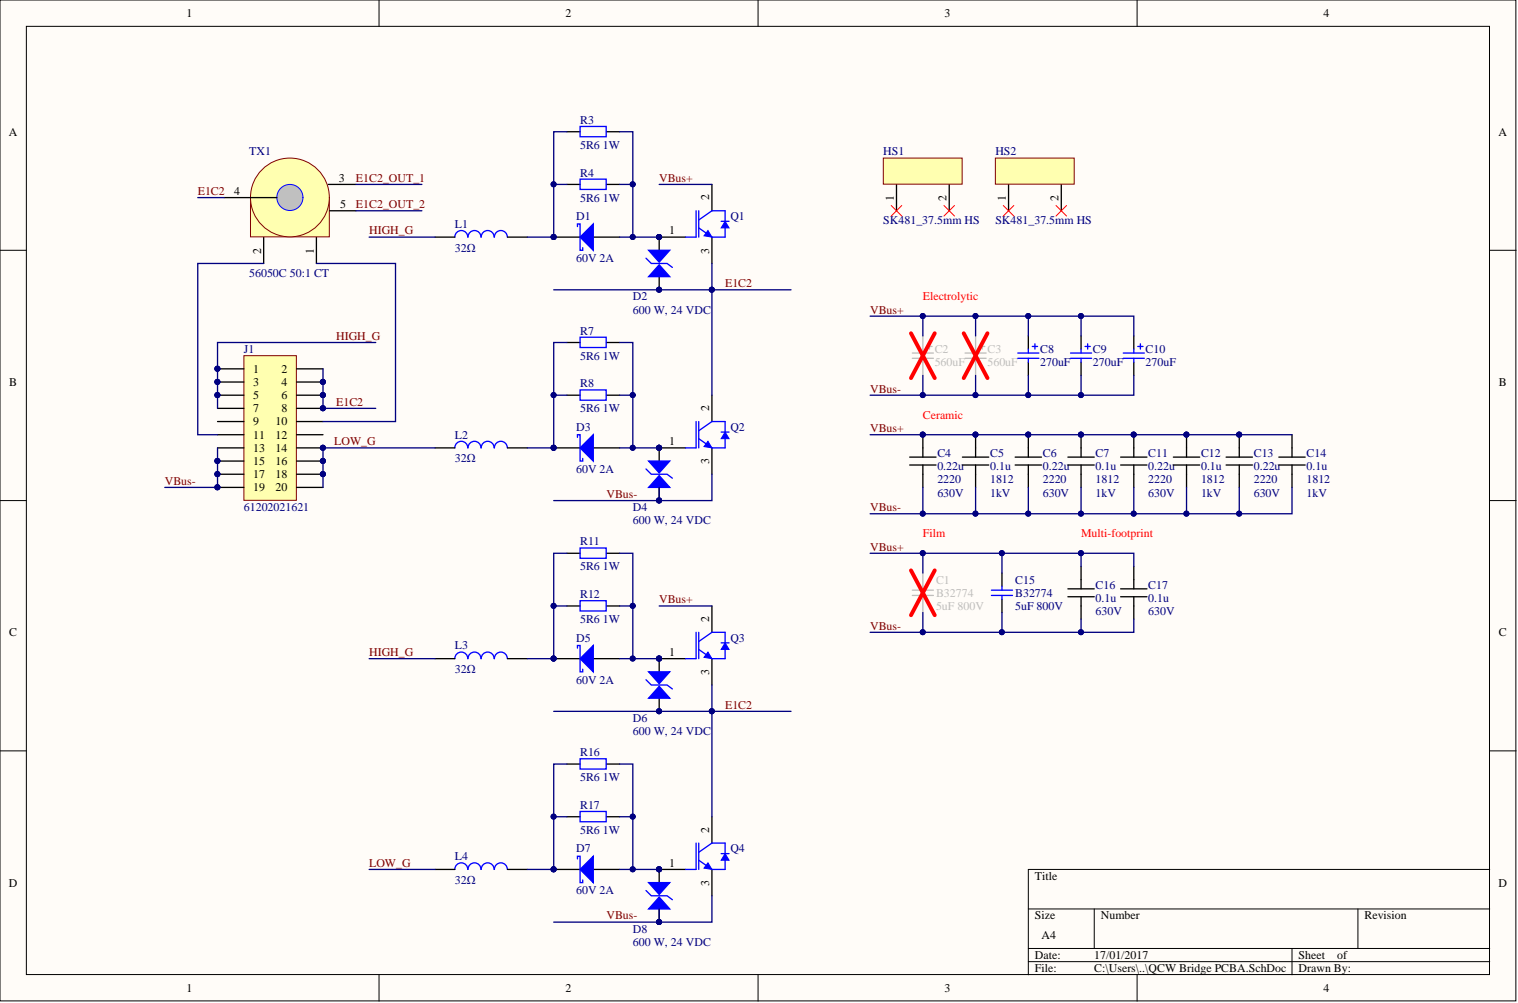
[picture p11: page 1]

J1
1 3 5 7 11 12 13 14 15 16 17 18 19 20


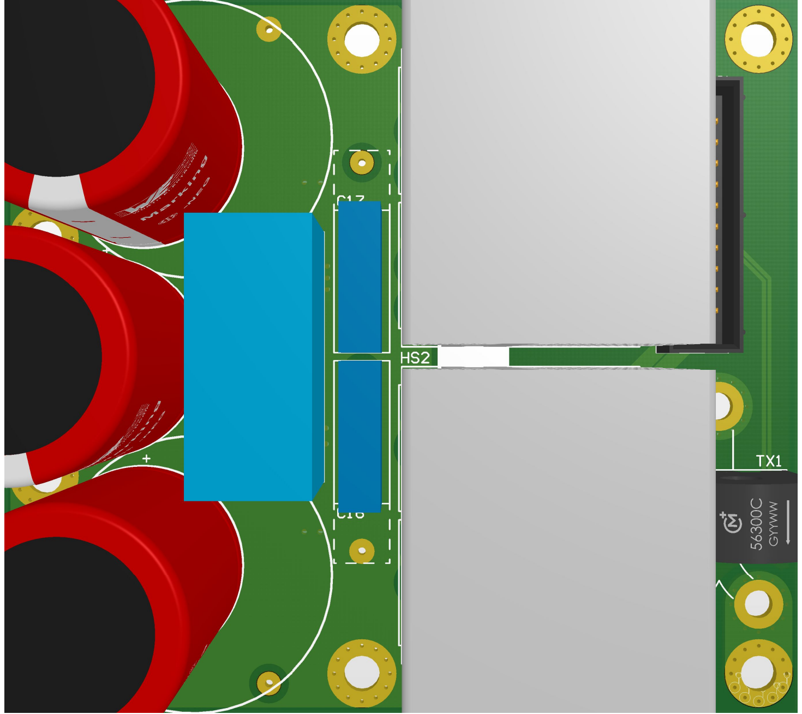
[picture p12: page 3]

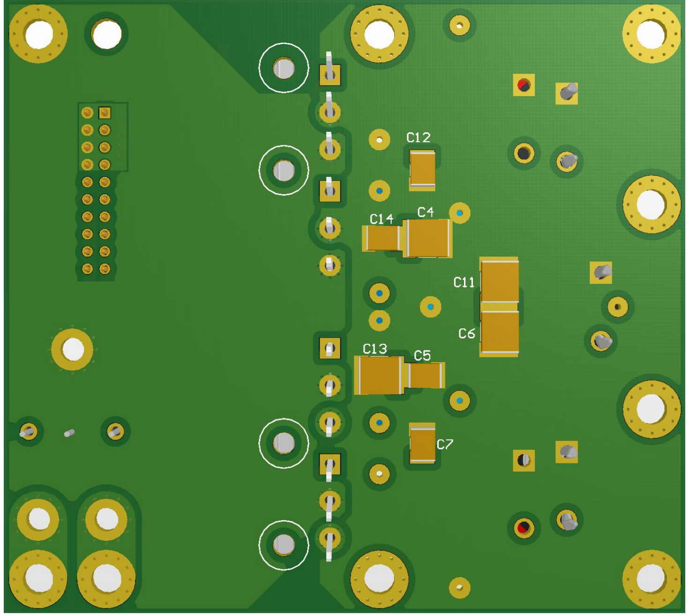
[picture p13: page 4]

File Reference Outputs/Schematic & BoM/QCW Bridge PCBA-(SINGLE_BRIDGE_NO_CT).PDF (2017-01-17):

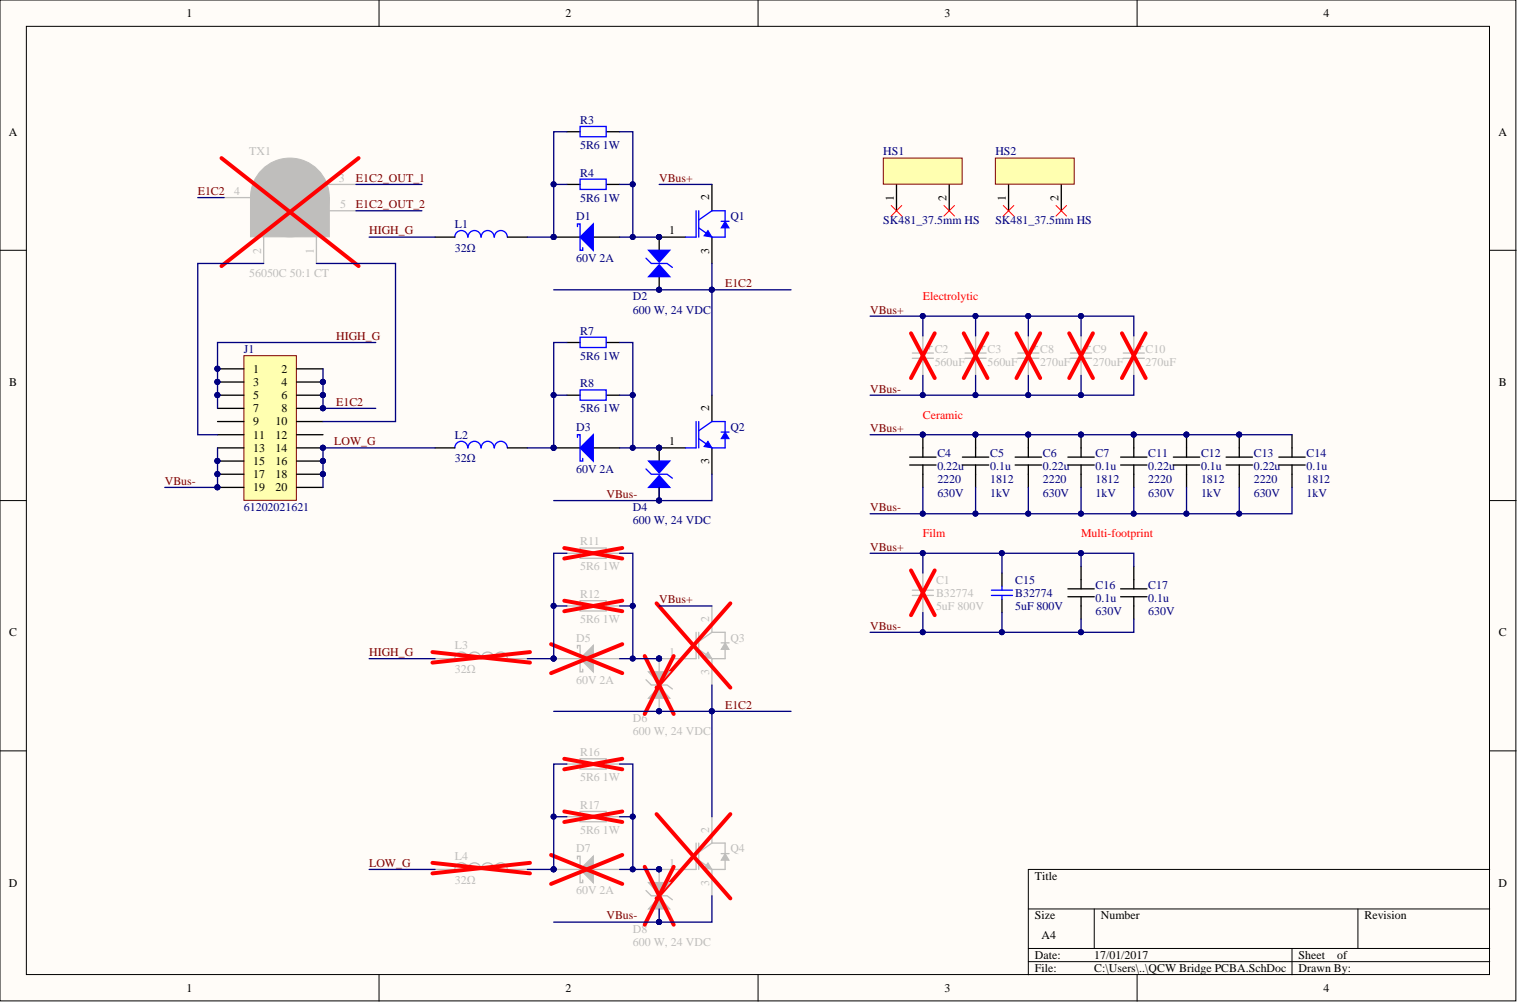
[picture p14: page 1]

J1
1 3 5 7 11 12 13 14 15 16 17 18 19 20




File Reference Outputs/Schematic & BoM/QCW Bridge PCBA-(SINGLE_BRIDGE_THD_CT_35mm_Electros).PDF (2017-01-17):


J1
1 3 5 7 11 12 13 14 15 16 17 18 19 20
